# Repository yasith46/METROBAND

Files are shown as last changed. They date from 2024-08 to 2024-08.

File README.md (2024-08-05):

<div align="center">  
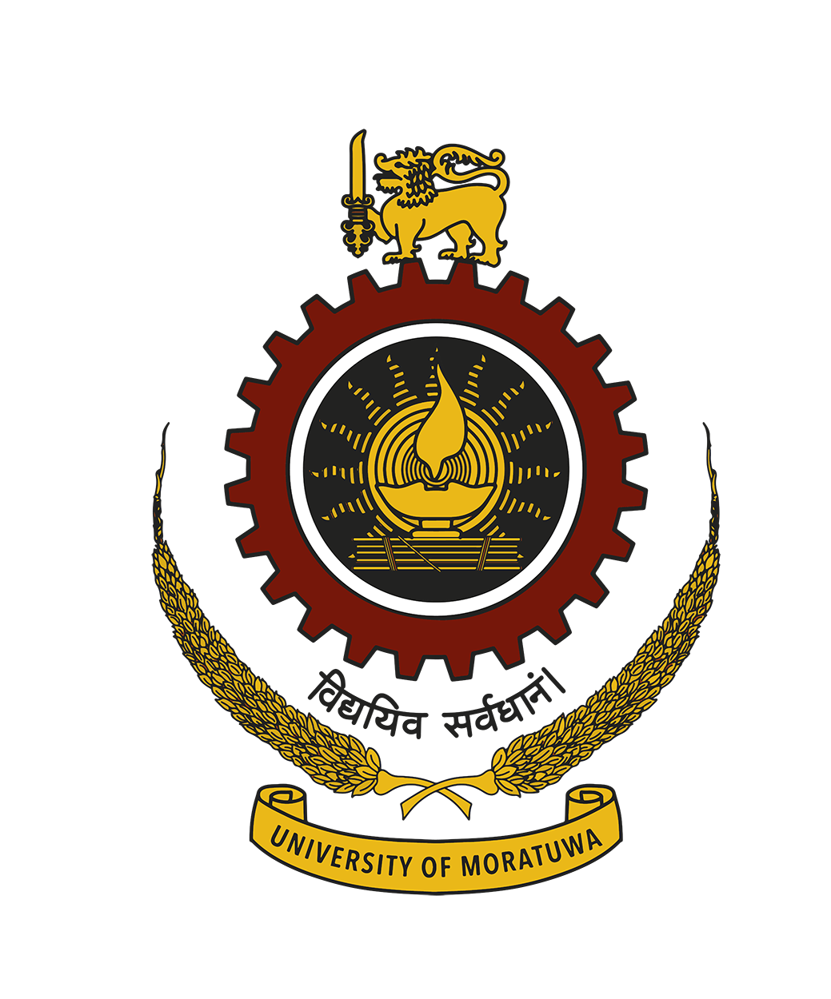
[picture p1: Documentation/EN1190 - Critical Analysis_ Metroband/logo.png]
    
    <h4>Department of Electronics and Telecommunications<br>University of Moratuwa</h4>
    <h2> METROBAND - The Metronome Wristband</h2>
    <br>Done in partial fulfillment of the requirements for the module <i>EN 1190 Engineering Design Project</i>
</div>

<br>Aim of this project is to create an alternative to the traditional Metronome, with a digitally controlled vibrating wristband. This repository contains all the documentation, code, schematics, PCB designs, and simulations of the project.
<br>Above works were done by Yasith Silva ([@yasith46](https://github.com/yasith46)), Bimsara Nawarathne ([@bimsaranawa](https://github.com/bimsaranawa)), Isuranga Senavirathne ([@isuranga1](https://github.com/isuranga1)) and Julian Silva ([@JulianSilva2001](https://github.com/JulianSilva2001)).

Demonstration of the project:<br><br>
<div align="center">
    <h3>Demonstration of the project:</h3><br>
    <a href="https://www.youtube.com/watch?v=N5GJq5FccDs" target="_blank">
        Demonstration of the Final Product
    </a>
</div>

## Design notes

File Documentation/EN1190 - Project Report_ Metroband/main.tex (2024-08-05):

\documentclass{article}
\usepackage{titlesec}
\usepackage[utf8]{inputenc}
\usepackage[a4paper, total={6in, 9in}]{geometry}
\usepackage{fancyhdr}
\usepackage{graphicx} % Add the graphicx package
\usepackage{lipsum} % For placeholder text
\usepackage{tikz}
\usepackage{cite}
\usepackage{bm}
\usepackage{acronym}
\usepackage{amsmath,amssymb,amsfonts}
\usepackage{algorithmic}
\usepackage{graphicx}
\usepackage{caption}
\usepackage{subcaption}
\captionsetup{font=small, labelfont=bf}
\captionsetup[sub]{labelsep=period, subrefformat=brace}
\usepackage{tikz}
\usepackage{textcomp}
\usepackage{xcolor}
\usepackage[numbers]{natbib}
\bibliographystyle{ieeetrann}
\usepackage{subfig}
\usepackage{svg}
\usepackage{tikz,pgfplots,pgfplotstable}
\pgfplotsset{compat=1.9} % set to 1.8 to get old behaviour
\usepackage{subfigure}
\usepackage{paralist}
\usepackage{longtable}

% Set up page headers and footers
\pagestyle{fancy}
\fancyhf{}
\rhead{ }
\rhead{team MOSFETS}
\lhead{Metroband - The Metronome Wristband}
\cfoot{\thepage}

% Redefine the abstract environment to be single column
\renewenvironment{abstract}
{\par\noindent\textbf{\abstractname}\ \ignorespaces}{\par}

% Redefine section format
\titleformat{\section}
{\normalfont\Large\bfseries}{\thesection}{1em}{}

\begin{document}
	
	% Cover Page
	\begin{titlepage}
		
		\centering
		\vspace*{0.5cm}
		 % Replace with the path to your university logo
		\par\vspace{0.02cm}
		Department of Electronic \& Telecommunication Engineering
  
            University of Moratuwa, Sri Lanka.
		\par\vspace{4cm}
		{\LARGE\bfseries Project Report:}\\{\LARGE Metroband - The Metronome Wristband\par}
		\vspace{4cm}
		\begin{tabular}{l l}
			& \\
            \multicolumn{2}{c}{\textbf{team MOSFETS}}\\
            210415N	&	Navarathne D.M.G.B.\\
            210594J &	Senevirathne I.U.B.\\
            210608J &	Silva L.J.J.P.\\
            210609M	&	Silva M.K.Y.U.N. \\
		\end{tabular}\\
		\vspace{1.3cm}
            {Submitted in partial fulfillment of the requirements for the module\par}
		{EN 1190 Engineering Design Project\par}
	
		\vspace{0.5cm}
		{\large 06/08/2024\par}
		\vfill
	\end{titlepage}

        \newpage
        \tableofcontents
	\newpage
	
        \section{Introduction}
        The aim of this project is to design and develop a pulsating wristband according to a given BPM to give a better experience for beginner, intermediate or professional musicians. This project is undertaken by a team of four engineering undergraduates from the University of Moratuwa. The following report provides details of the progress made towards achieving the project objectives.
        
        \subsection{The Problem, and the Motivation to Solve it}
        \subsubsection{Problem Definition}
        In music, BPM is the speed of a musical piece. It determines the overall energy and the feel of the musical performance. It is measured in Beats per Minute (BPM). In practicing to master a piece, it is crucial for one to be able to play it in time. This is even more important when playing in groups, where the whole group must play it at the same BPM. It is often maintained throughout the music using a metronome, in-ear headphones, or a conductor.\\

        One of the major problems of musicians of both beginner and amateur levels, and sometimes even professionals is, keeping up the BPM while performing or practicing. For beginners, it brings great frustration as well as for many others when performing with a group it ruins the entire timing of the song. This often wastes a good fraction of the practice time.\\

        There are a few solutions to combat this. Namely:
        \begin{compactitem}
                \item Metronomes
                \item In-ear Headphones
        \end{compactitem}
        .\\
        But they too have their own potential problems and limitations which are listed below that have been complained about by many users:

        \begin{itemize}
                \item \textbf{External noise:} In noisy environments, metronomes can be hard to hear, and in-ear headphones can isolate the player from outside sounds, making it challenging to play with others.
                \item \textbf{Distraction:} Some musicians may find metronomes to be distracting or irritating, especially if they are practicing for extended periods of time. Over time, in-ear headphones may also result in ear discomfort or tiredness.
                \item \textbf{Inaccessibility:} Due to physical constraints or disabilities like hearing impairments, some musicians may find it challenging to utilize conventional metronomes or headphones, which have been recognized as a major issue.
                \item \textbf{Cost:} Metronomes and in-ear headphones can be expensive which will not make it feasible for many users.
        \end{itemize}

        \subsubsection{Motivation for our solution}
        Since all our group members are practicing music up to some extent, we have all felt the need of addressing this problem. However, to gather more information about this matter we carried out an online survey which spanned out not only through local music societies but also across multiple global music societies as well. The communities from which we gathered information are as follows:

        \begin{compactitem}
                \item Classical Music Society (CMS) of the University of Moratuwa
                \item Discord servers such as ‘We are engineers’ of Mattias Krantz and ‘RoomieOfficial’ of Joel Berghult; two popular Swedish music YouTubers
                \item Peer musician groups
                \item Social media such as X (formerly Twitter) and Facebook
                \item Personal contacts
        \end{compactitem}

        \newpage
        The results of our survey are as follows:

        \begin{figure}[htpb]
            \centering
            \begin{minipage}{0.45\textwidth}
                \centering
                \begin{subfigure}{\textwidth}
                    \centering
                    \begin{tikzpicture}
                        \begin{axis}[
                            ybar stacked,
                            width=7cm,
                            xlabel={Categories},
                            ylabel={Values},
                            legend style={at={(0.5,-0.65)}, anchor=north, legend columns=2},
                            symbolic x coords={Very Hard, Hard, Neutral, Easy, Very Easy},
                            xtick=data,
                            x tick label style={rotate=45, anchor=east, xshift=-1.5mm, yshift=-2mm},
                            nodes near coords={},
                            nodes near coords align={vertical},
                            ]
                            \addplot+[bar width=0.4cm] coordinates {(Very Hard, 0) (Hard, 1) (Neutral, 3) (Easy, 0) (Very Easy, 2)};
                            \addplot+[bar width=0.4cm] coordinates {(Very Hard, 2) (Hard, 3) (Neutral, 7) (Easy, 6) (Very Easy, 0)};
                            \addplot+[bar width=0.4cm] coordinates {(Very Hard, 1) (Hard, 4) (Neutral, 18) (Easy, 27) (Very Easy, 7)};
                            \addplot+[bar width=0.4cm] coordinates {(Very Hard, 0) (Hard, 0) (Neutral, 1) (Easy, 4) (Very Easy, 1)};
                            \legend{Played in past, Beginner, Intermediate, Professional}
                        \end{axis}
                    \end{tikzpicture}
                \end{subfigure}
            \end{minipage}
            \hspace{1cm}
            \begin{minipage}{0.45\textwidth}
                \centering
                \begin{subfigure}{\textwidth}
                    \centering
                    \begin{tikzpicture}
                        \begin{axis}[
                            ybar stacked,
                            width=7cm,
                            xlabel={Categories},
                            ylabel={Values},
                            legend style={at={(0.5,-0.65)}, anchor=north, legend columns=2},
                            symbolic x coords={Very Ineffective, Ineffective, Neutral, Effective, Very Effective},
                            xtick=data,
                            x tick label style={rotate=45, anchor=east, xshift=-1.5mm, yshift=-2mm},
                            nodes near coords={},
                            nodes near coords align={vertical},
                            ]
                            \addplot+[bar width=0.4cm] coordinates {(Very Ineffective, 1) (Ineffective, 1) (Neutral, 2) (Effective, 0) (Very Effective, 0)};
                            \addplot+[bar width=0.4cm] coordinates {(Very Ineffective, 1) (Ineffective, 0) (Neutral, 4) (Effective, 4) (Very Effective, 2)};
                            \addplot+[bar width=0.4cm] coordinates {(Very Ineffective, 6) (Ineffective, 8) (Neutral, 3) (Effective, 17) (Very Effective, 14)};
                            \addplot+[bar width=0.4cm] coordinates {(Very Ineffective, 0) (Ineffective, 0) (Neutral, 1) (Effective, 1) (Very Effective, 4)};
                            \legend{Played in past, Beginner, Intermediate, Professional}
                        \end{axis}
                    \end{tikzpicture}
                \end{subfigure}
            \end{minipage}
            \caption{Comparison of Stacked Bar Charts A and B}
        \end{figure}

        \subsection{Our Solution}
        As a solution to these critical problems and limitations that have arisen, after thorough observation and research, we have decided that the best solution would be a wristband that is pulsating according to a given BPM which we named \textbf{‘Metroband’}. The reasonings for our solution are listed as follows:

        \begin{itemize}
                \item \textbf{Convenience:} A wristband is portable and wearable, so it can be used anywhere and anytime without the need for a separate device. This can be especially useful for musicians who need to maintain a consistent BPM while on the go, such as during rehearsals or performances.
                \item \textbf{Discreetness:} A vibrating wristband produces a subtle, tactile cue that only the wearer can feel, unlike a metronome which produces an audible sound that can be distracting or disruptive in certain settings, such as recording studios or quiet performance venues.
                \item \textbf{Personalization:} A wristband can be personalized to the user's preferences, allowing them to set their own BPM and adjust the intensity of the vibrations to match their playing style or musical genre.
                \item \textbf{Accessibility:} A wristband can be a useful tool for musicians with hearing impairments or who prefer to play without auditory distractions, as it provides a non-auditory way to keep track of the BPM.
        \end{itemize}

        \section{Technical feasibility}
        The physical appearance of the Metroband would be similar to a smartwatch which could be easily worn on the wrist with simply one knob to do all the operations. Moving onto the internal structure of the Metroband, it is basically built around a single dual-core microcontroller that takes inputs from the knob and displays the relevant BPM on an LCD display. All these devices are powered by a rechargeable Lithium-Ion battery.\\
        
        The required components such as ESP32, rotary encoders, LCD TFT displays, MCP73831 are readily available on the market, both on online vendors as well through local sellers. Further, thorough documentation of these components is available online.\\
        
        We have planned on to programme the ESP32 using another ESP32 Development Kit, using the Arduino IDE. Due to the availability of well optimized free and open-source libraries, the implementation of Bluetooth can be done way far more efficiently.

        \section{Product Architecture}
        Below shown is a block diagram of the abstract modules in the Metroband. It has clearly mentioned the connections, data flow directions, and some data on what data are communicated between the modules that  are described earlier.

            \begin{figure}[!htb]
                \centering
                \begin{tikzpicture}
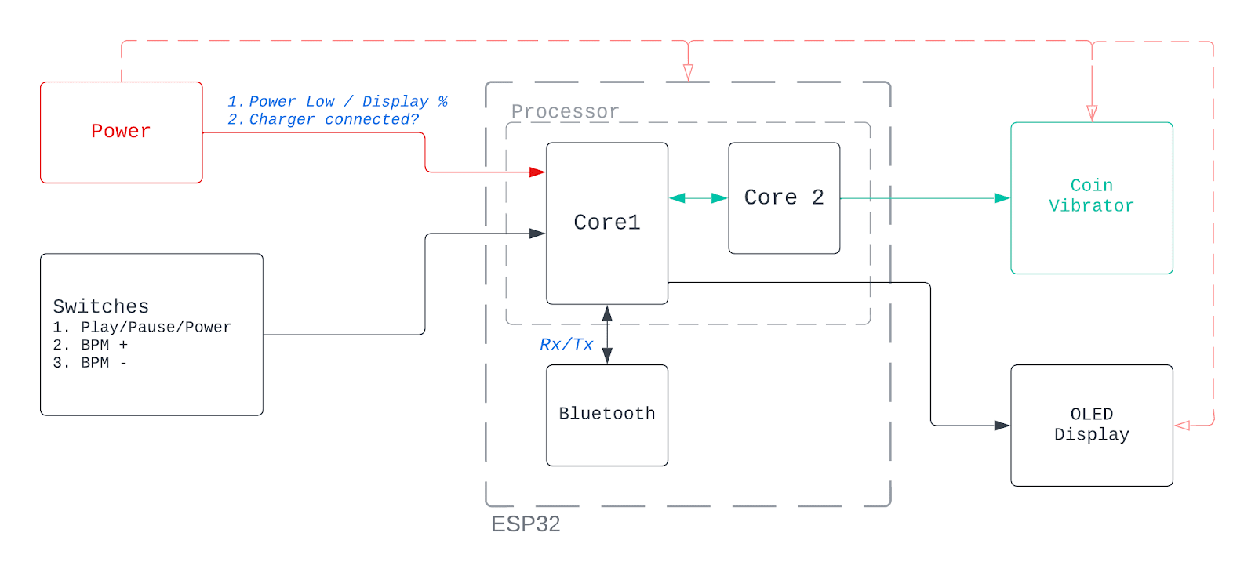
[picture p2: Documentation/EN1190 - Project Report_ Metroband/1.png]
                    \node at (0.5,-0.2){};
                \end{tikzpicture}
                \caption{Product architecture}
            \end{figure}

        Functionalities of each module is as follows:
        \subsection{ESP32 Micro-controller}
        This is the microcontroller that we will be using for our product. Each operation is split into tasks, and the ESP32 executes them according to the priority set by the code. Also, the Bluetooth module allows the device to communicate with the mobile app.

        \subsection{Switches}
        As the switch we are using a rotary encoder. Mainly because it can be used to many functionalities. By rotating it clockwise and counterclockwise, we can increase or decrease the BPM. By pressing and depressing it, we can play/pause sending pulses to the vibrating motor. Long press will switch on/off the devices.

        \subsection{LCD TFT Display}
        This will be the display used to mainly show the BPM. Other than that, it will show the Bluetooth connectivity and battery percentage as well.

        \subsection{Coin Vibrator}
        This is the vibrating motor used in our device. It vibrates according to the pulses sent by the microcontroller. In fact, the pulses will be sent through a transistor in switch mode which will give the full power of the battery to the motor.

        \subsection{Power}
        We will be using a rechargeable Lithium-Ion battery to power up all the devices in our product. To handle the charging process, there will be charging IC as well.

        \section{Sketches}
        \subsection{Initial Sketches}
            \begin{figure}[!htb]
                \centering
                \begin{tikzpicture}
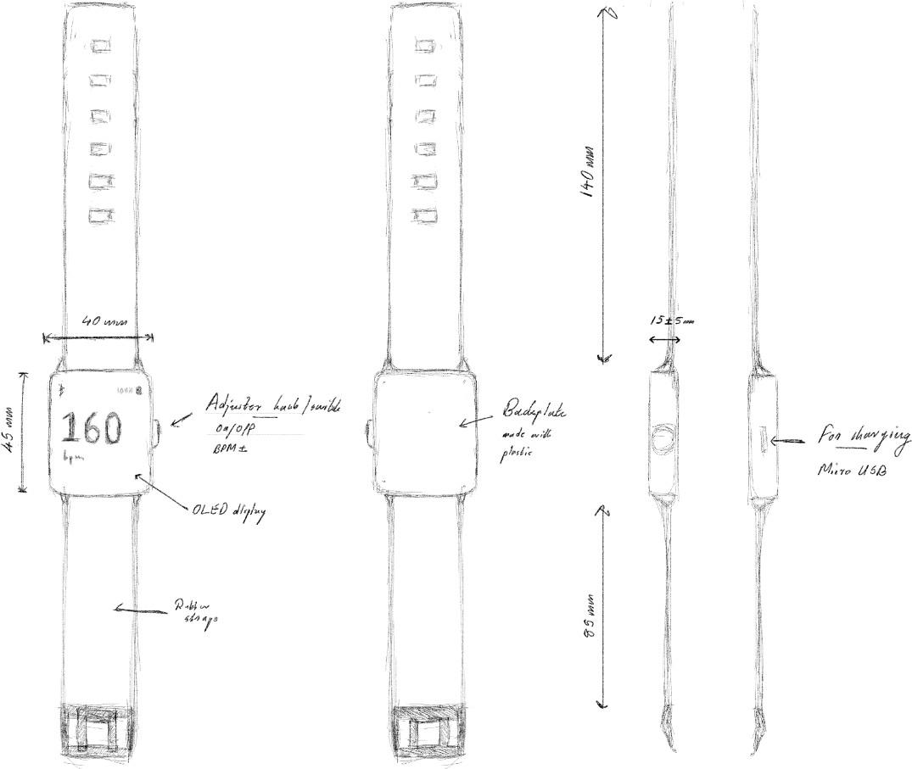
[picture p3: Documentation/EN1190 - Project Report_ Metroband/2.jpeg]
                    \node at (0.5,-0.2){};
                \end{tikzpicture}
                \caption{Initial sketch}
            \end{figure}

        \subsection{Final Design}

        \begin{minipage}{\linewidth}
                \centering
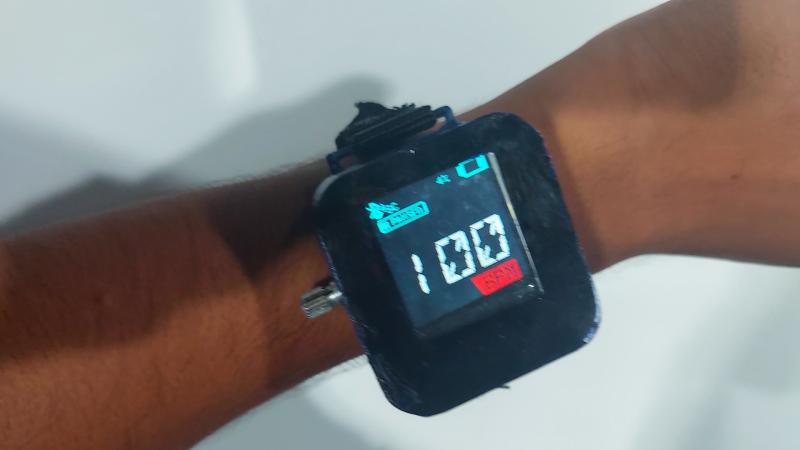
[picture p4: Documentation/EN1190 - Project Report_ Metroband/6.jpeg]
                
                \hspace{0.005\linewidth}
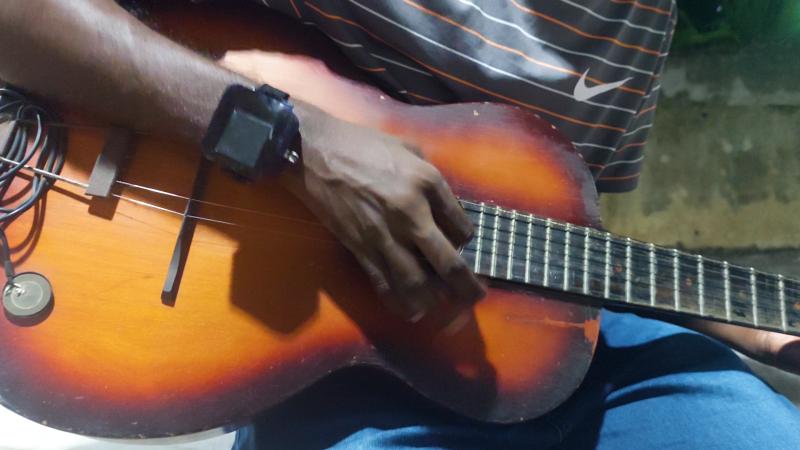
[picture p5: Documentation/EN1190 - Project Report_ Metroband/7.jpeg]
                
                \captionsetup{justification=centering} % Center-align the caption
                \captionof{figure}{Final design, worn on hand}
            \end{minipage}

        \section{Finalized Project Details}
        \subsection{Schematic and PCB}
        \begin{figure}[!htb]
                \centering
                \begin{tikzpicture}
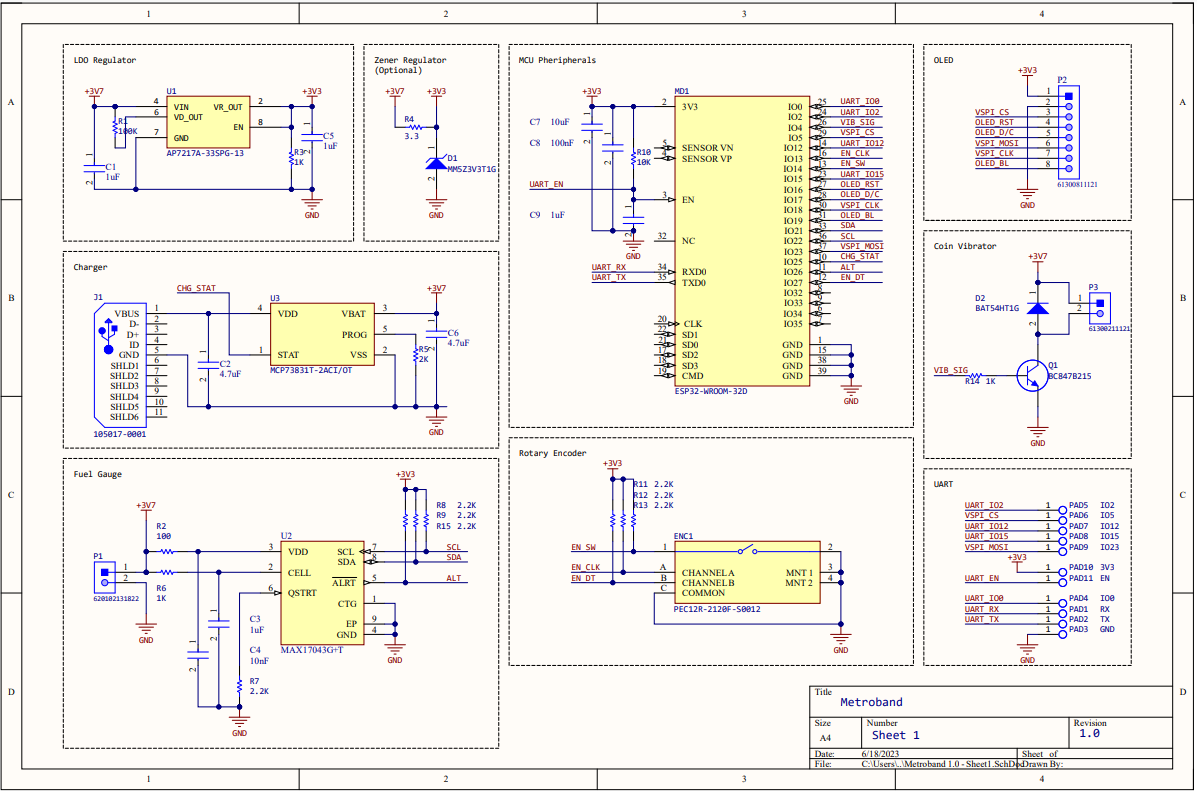
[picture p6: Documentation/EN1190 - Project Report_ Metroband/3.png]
                    \node at (0.5,-0.2){};
                \end{tikzpicture}
                \caption{Schematic Diagram}
                \label{schematic}
            \end{figure}
        \begin{figure}[!htb]
                \centering
                \begin{tikzpicture}
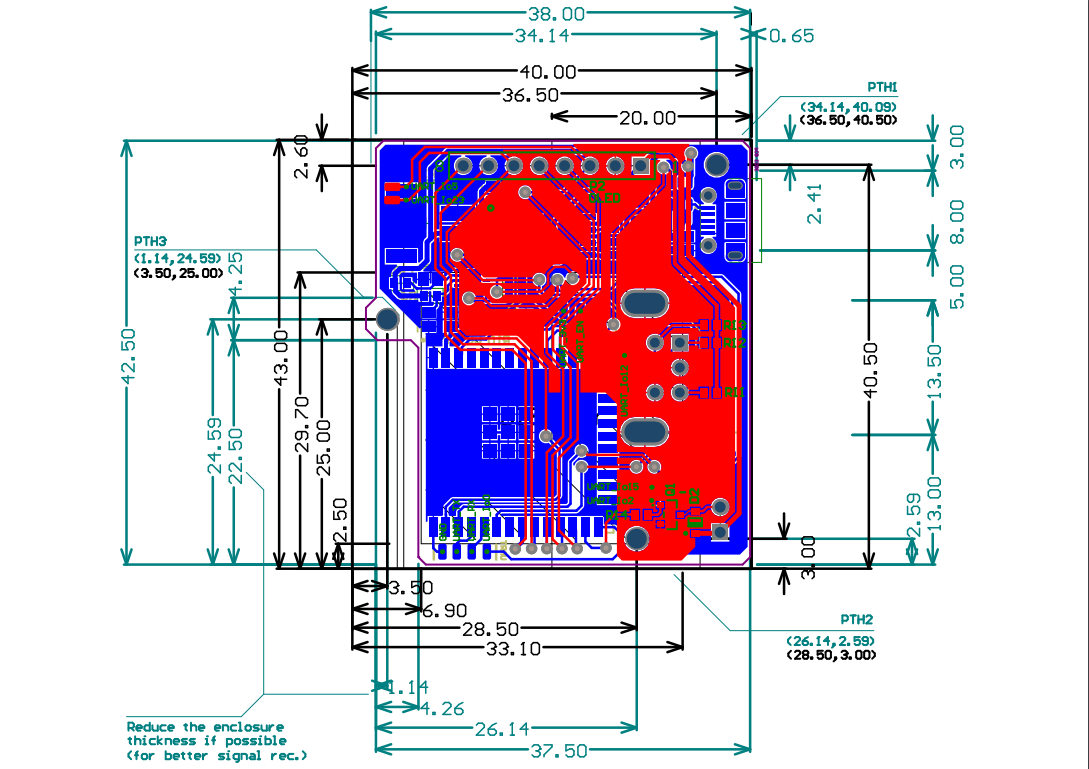
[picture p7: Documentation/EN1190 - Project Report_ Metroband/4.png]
                    \node at (0.5,-0.2){};
                \end{tikzpicture}
                \caption{PCB overview}
                \label{pcb}
            \end{figure}
        \begin{figure}[!htb]
                \centering
                \begin{tikzpicture}
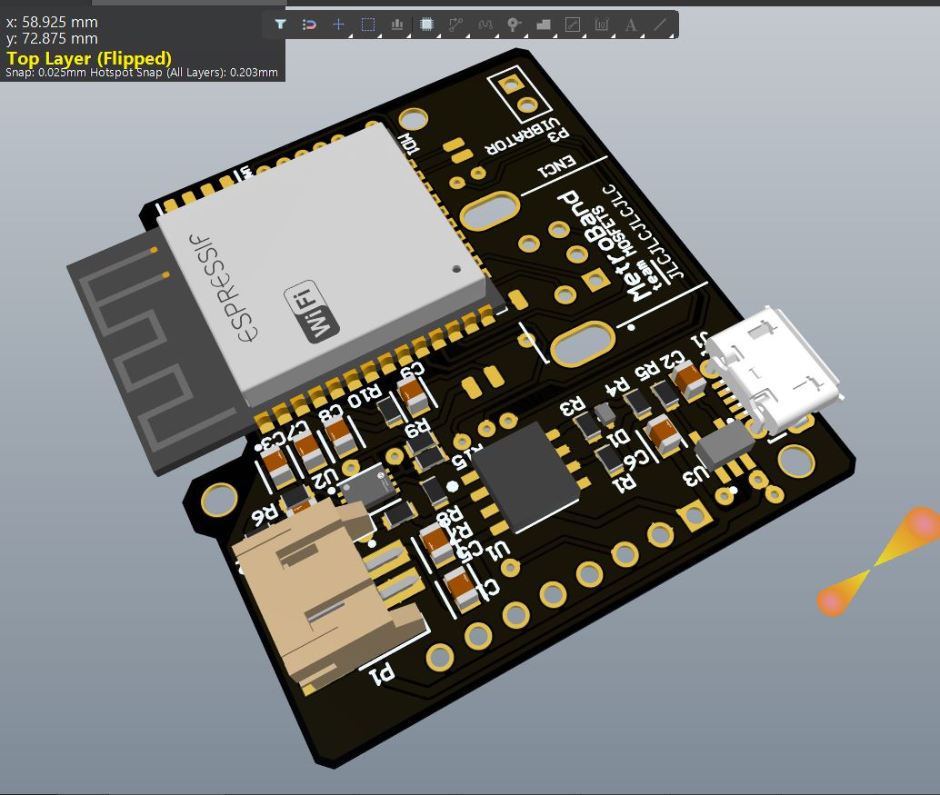
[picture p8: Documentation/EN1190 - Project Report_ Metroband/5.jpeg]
                    \node at (0.5,-0.2){};
                \end{tikzpicture}
                \caption{3D view of the PCB}
                \label{pcb3d}
            \end{figure}
        The circuit diagram of the product is shown below in Figure \ref{schematic}. It was designed with a voltage regulator as the battery gives a voltage of 4.2V when fully charged, and the ESP32 requires 3.6-2.2V. Although the IC was included in the circuit, due to predictions of local unavailability of the ICs we included a slot for a zener diode of 3.3V to be soldered as well.\\
        
        Several modifications were done for the display, as we chose a TFT display rather than an OLED display.\\
        
        All the functionalities of the circuit are controlled by the rotary encoder and its inbuilt push-button (manually) and via bluetooth.\\
        
        The PCB in size is 42.5mm x 38mm as it requires to be small enough to fit on a wrist. Hence it was required to use SMD components. also the required clearances for the antenna of the ESP32 were kept. ESP32 was planned to be programmed with the UART converter of a development board, and for this purpose several test pads were kept so wires could be soldered and it desoldered at the last minute.

        \subsection{Coding}
        For coding we used the ESP IDF. We carried out the tasks separately in the singular core rather than carrying all the tasks in a singular loop while adjusting their priorities.
        Also we had to use multiple libraries in order to code the parts related to bluetooth, display and other functions of the ESP32. Further, we had to design the bitmap of the icons as well as the numbers, as we used a 16-segment display font.

        \subsection{Enclosure Design}
        The enclosure was designed using SOLIDWORKS 2023.We needed to get the enclosure as detailed as possible with minimum dimensions.\\

        \begin{minipage}{\linewidth}
                \centering
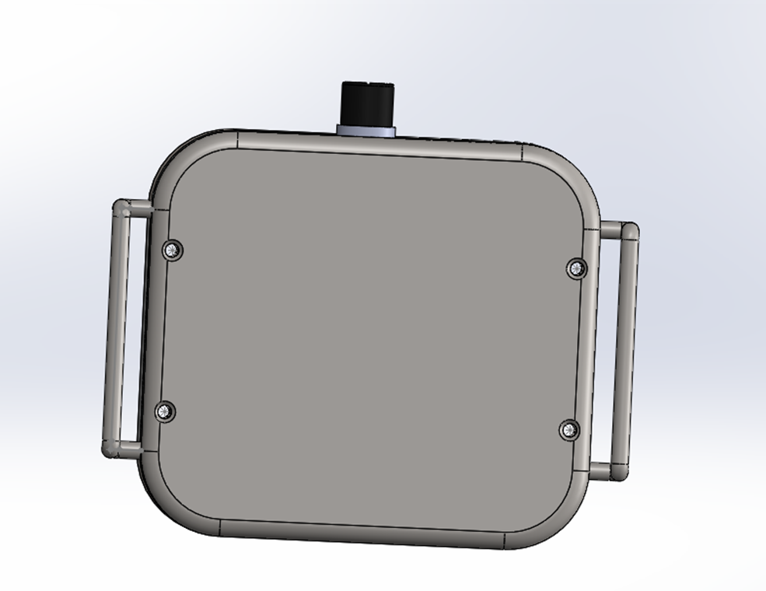
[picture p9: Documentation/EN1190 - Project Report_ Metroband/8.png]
                
                \hspace{0.005\linewidth}
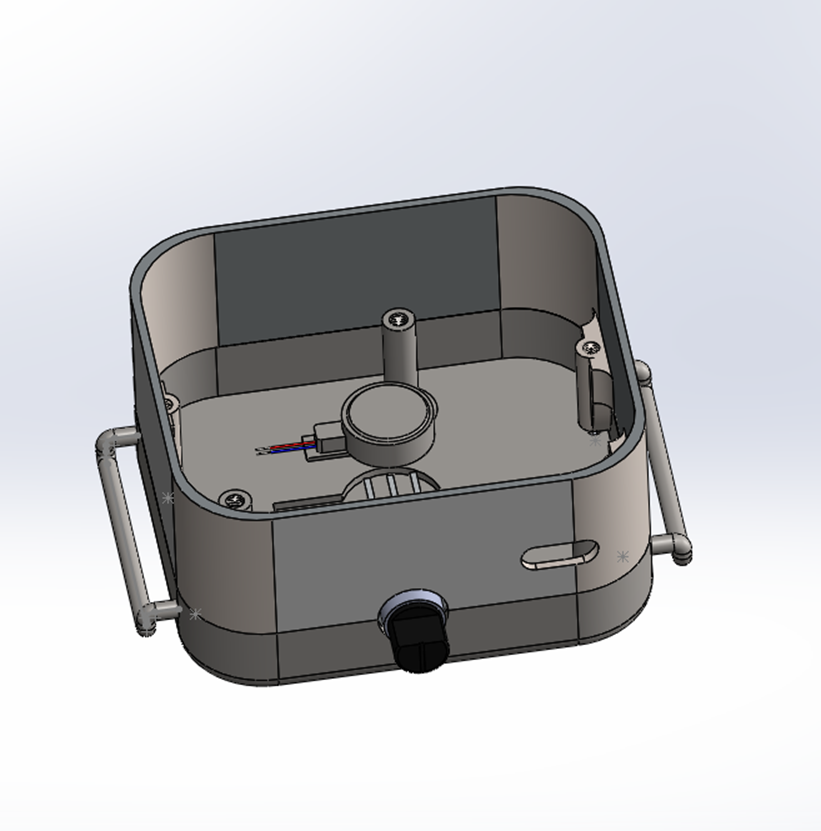
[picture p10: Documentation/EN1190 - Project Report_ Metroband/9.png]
                
                \hspace{0.005\linewidth}
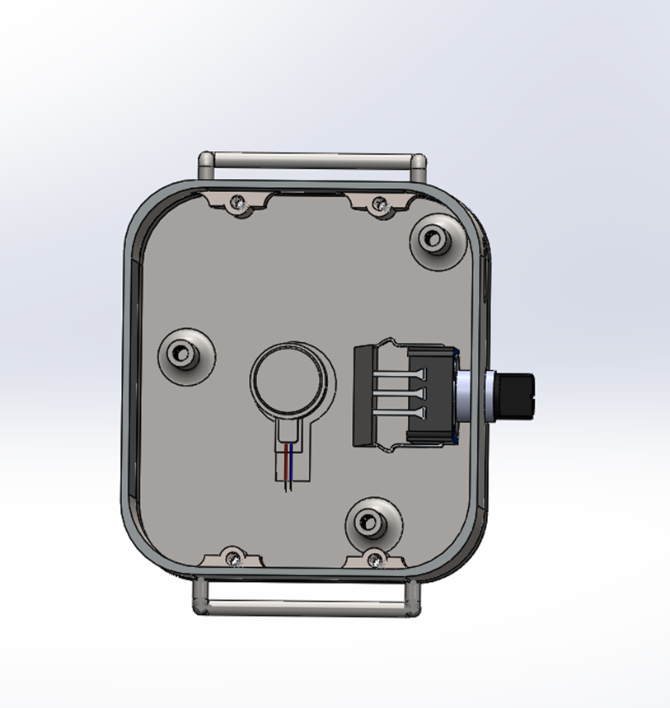
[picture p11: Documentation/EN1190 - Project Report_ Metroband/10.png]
                
                \captionsetup{justification=centering} % Center-align the caption
                \captionof{figure}{Enclosure SOLIDWORKS design}
            \end{minipage}

        \newpage
        \section{Project Budget}
        \begin{longtable}{|l|r|r|r|}
        
        \hline
        \textbf{Item} & \textbf{Quantity} & \textbf{Unit Price} & \textbf{Price} \\
        \hline
        \endfirsthead
        
        \hline
        \textbf{Item} & \textbf{Quantity} & \textbf{Unit Price} & \textbf{Price} \\
        \hline
        \endhead
        
        \hline
        \endfoot
        
        \hline
        \endlastfoot
        
        Coin vibrator & 1 & RS.300 & RS.300 \\
        Battery & 1 & Rs.450 & Rs.450 \\
        TFT display unit & 1 & Rs.1400 & Rs.1400 \\
        Regulator IC & 1 & Rs.185 & Rs.185 \\
        Fuel gauge IC & 1 & Rs.500 & Rs.500 \\
        Charger IC & 1 & Rs.350 & Rs.350 \\
        mini USB slot & 1 & Rs.150 & Rs.150 \\
        PCB Design and Printing & - & - & Rs.500 \\
        Enclosure Printing & - & - & Rs.760 \\
        Padding and Straps & - & - & Rs.250 \\
        Resistors & 6 & - & Rs.50 \\
        Capacitors & 8 & - & Rs.50 \\
        Transistor & 1 & Rs.5 & Rs.5 \\
        Esp 32 module & 1 & Rs.700 & Rs.700 \\
        Rotary Encoder & 1 & Rs.350 & Rs.350 \\
        \hline
        \textbf{Total cost for components} & - & - & \textbf{Rs.5995.00} \\
        \textbf{Number of units} & - & - & \textbf{200} \\
        \textbf{Marketing and sales cost} & - & - & \textbf{Rs.10,000} \\
        \textbf{Profit per unit} & - & - & \textbf{Rs.5000} \\
        \textbf{Product price} & - & - & \textbf{Rs.10,000} \\
        \hline
        \end{longtable}

        \section{Future Developments}
        \subsection{Size}
        Currently we have identified that the size of the prototype could be a hindrance for some musicians. Hence we intend to reduce the size of the watch to a wearable size. In order to do this we have come across few methods:
        \begin{itemize}
                \item Using a TFT display without the breakout PCB, as the PCB and the pin headers add 3 mm to the height
                \item By using a smaller rotary encoder which is usually used in applications such as smartwatches, we can further reduce the height
                \item By resorting to a further compact design in designing the PCB, and outsourcing the soldering of components to a ‘pick and place’ services provider, the length and width of the apparatus could be reduced
                \item By choosing a thinner battery, the height could be further reduced
        \end{itemize}

        \subsection{Display}
        Currently we have included a 1.44 inch TFT. As this does not cover the complete front face of the watch, we have identified that it would be better to choose a display slightly larger than the current display, which would be rather aesthetically pleasing to the consumer.\\
        Further, the current display elements are designed in such a way so they are reminiscent of the classic ‘Vacuum Fluorescent Displays’, which would be further improved in the design phase to further resemble.

        \subsection{Vibration Intensity}
        For musicians who play rather delicate instruments such as piano or violin, more subtle vibrations are required. And some users would need a user set vibration intensity for the device to vibrate with. For this, we have identified using a PWM signal with an adjustable duty cycle as a solution. The code will be changed accordingly to achieve this, and a setting to change the intensity would be added to the mobile app. 

        \subsection{USB C port}
        Recently, USB-C has become the standard connector for the devices. Hence USB-C cables are becoming more available. Hence by changing the Micro-USB to a USB-C port, we give the consumer the opportunity to use any charging cable as they would please.

        \subsection{Battery}
        With the current battery, the device’s charge remains up to 5 hours when in use. This could be further improved with using a battery with a better capacity, while retaining (or preferably reducing) the size.

        \subsection{Enclosure}
        The enclosure will have a design makeover, with a newer, more attractive design which suits the modern market. The straps would be replaced with more comfortable silicone straps, and the body would have a more sleek design.

        \subsection{Mobile Application}
        The app is to be  featured with additional features. The vibration intensity can be set by the mobile app which will make it feasible for playing different instruments that require different vibration intensities. Moreover, presets can be saved in the mobile app so that the Metroband can help the musicians in playing music that changes its beat in-between or  gradually. Additionally, playlists can be saved in the mobile app. Also the UI design will be improved.

        \section{Marketing, Sales, and After-sales}
        \subsection{Marketing}
        We’ll be focusing our marketing effort on musicians, music students, choirs and orchestras. The silent and convenient alternative to traditional metronomes, allowing for uninterrupted practice sessions will be highlighted which will be offered by the “Metroband”.\\
        
        We’ll be engaging with online communities, forums, Facebook, WhatsApp, twitter and other social media groups that are dedicated to musicians and music enthusiasts. We will be participating in discussions, sharing valuable insights while promoting the “Metroband” as a useful tool not only for the musicians seeking an innovative way to keep the BPM without the noise, but also for the musicians with hearing disorders to keep up their beat in time.\\
        
        We’ll be also creating engaging creative videos that demonstrate the functionality, the benefits and the need of the “Metroband” for the musicians. Moreover, how the wristband can be synchronized with various instruments and used during practice sessions can be shown. These videos will be shared on our website and social media platforms.\\
        
        Also we were able to present our product at the EXMO exhibition which was held on 27th to 29th of July, which gave a great exposure for our product, which also gave us the opportunity to connect with potential investors.

        \subsection{After-sales}
        Encourage the customers to provide feedback and testimonials about their experience using the “Metroband”. Positive reviews can be highlighted and posted on social media channels to gain the trust and attract new customers. Negative reviews will be carefully comprehended, and prompt actions will be taken to resolve them.\\
        
        Because the ESP32 board is used here we are able to code it so that it is able to receive over the air firmware updates (OTA updates). Because of this even more functionalities can be added even after the sale of the product.\\
        
        The product's disposability is also taken into consideration. There will be detailed instructions on how to properly dispose of the wristbands, including details on recycling possibilities. Any harmful or poisonous materials can be reused or given to electronic shops for reuse because they are not used in the electronic component. Additionally, details will be provided on how customers can return straps so that we can recycle or re-purpose them.\\

        \section{Task Allocation}

        \begin{itemize}
            \item \textbf{Nawarathna D.M.G.B}
                \begin{itemize}
                    \item Coding
                    \item PCB Design
                    \item Vibrating Motor Module
                \end{itemize}

            \item \textbf{Senevirathne I.U.B}
                \begin{itemize}
                    \item OLED Display Module
                    \item Web App Development
                    \item Budget Management
                    \item Enclosure Design
                \end{itemize}

            \item \textbf{Silva L.J.J.P}
                \begin{itemize}
                    \item Microcontroller and the Peripherals
                    \item Enclosure Design
                    \item Market Research
                \end{itemize}
        
            \item \textbf{Silva M.K.Y.U.N}
                \begin{itemize}
                    \item PCB Design
                    \item Schematic
                    \item Fuel Gauge 
                    \item Coding
                \end{itemize}
        \end{itemize}

\end{document}

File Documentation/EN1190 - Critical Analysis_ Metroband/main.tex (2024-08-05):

\documentclass{article}
\usepackage{titlesec}
\usepackage[utf8]{inputenc}
\usepackage[a4paper, total={6in, 9in}]{geometry}
\usepackage{fancyhdr}
\usepackage{graphicx} % Add the graphicx package
\usepackage{lipsum} % For placeholder text
\usepackage{tikz}
\usepackage{cite}
\usepackage{bm}
\usepackage{acronym}
\usepackage{amsmath,amssymb,amsfonts}
\usepackage{algorithmic}
\usepackage{graphicx}
\usepackage{caption}
\usepackage{subcaption}
\captionsetup{font=small, labelfont=bf}
\captionsetup[sub]{labelsep=period, subrefformat=brace}
\usepackage{tikz}
\usepackage{textcomp}
\usepackage{xcolor}
\usepackage[numbers]{natbib}
\bibliographystyle{ieeetrann}
\usepackage{subfig}
\usepackage{svg}
\usepackage{tikz,pgfplots,pgfplotstable}
\pgfplotsset{compat=1.9} % set to 1.8 to get old behaviour
\usepackage{subfigure}
\usepackage{paralist}
\usepackage{longtable}

% Set up page headers and footers
\pagestyle{fancy}
\fancyhf{}
\rhead{ }
\rhead{team MOSFETS}
\lhead{Metroband - The Metronome Wristband}
\cfoot{\thepage}

% Redefine the abstract environment to be single column
\renewenvironment{abstract}
{\par\noindent\textbf{\abstractname}\ \ignorespaces}{\par}

% Redefine section format
\titleformat{\section}
{\normalfont\Large\bfseries}{\thesection}{1em}{}

\begin{document}
	
	% Cover Page
	\begin{titlepage}
		
		\centering
		\vspace*{0.5cm}
		 % Replace with the path to your university logo
		\par\vspace{0.02cm}
		Department of Electronic \& Telecommunication Engineering
  
            University of Moratuwa, Sri Lanka.
		\par\vspace{4cm}
		{\LARGE\bfseries Critical Analysis:}\\{\LARGE Metroband\par}
		\vspace{4cm}
		\begin{tabular}{l l}
			& \\
            \multicolumn{2}{c}{\textbf{team MOSFETS}}\\
            210415N	&	Navarathne D.M.G.B.\\
            210594J &	Senevirathne I.U.B.\\
            210608J &	Silva L.J.J.P.\\
            210609M	&	Silva M.K.Y.U.N. \\
		\end{tabular}\\
		\vspace{1.3cm}
            {Submitted in partial fulfillment of the requirements for the module\par}
		{EN 1190 Engineering Design Project\par}
	
		\vspace{0.5cm}
		{\large 08/05/2024\par}
		\vfill
	\end{titlepage}

        \newpage
        The following report provides a critical analysis of the project for the design and development of the Metroband. The project aims to create a wristband that can pulse in sync with the tempo, providing a novel and engaging user experience. The design incorporates a microcontroller, a vibrating motor, and a display unit, all housed in a compact and comfortable wristband. The purpose of this report is to evaluate the success of the project in meeting its goals, as well as to identify any areas for improvement or further development.\\

        Below mentioned are the probable constraints and the suggested solutions to overcome:
        
        \section{Battery life}
        DC motors usually draw some more current than other components, specifically in the start of the rotation. Vibrator is something having a similar mechanism to a motor, and in giving the tempo it would have to start up the rotation several times corresponding to the Beats per Minute value. Hence it might draw a larger current, which might not be a good thing for some components, as well as drain the batteries quicker.\\
        
        This can be overcome by using the following strategies. 

        \subsection{Using Low power Bluetooth - built-in Bluetooth Low Energy chip in ESP32}

        \begin{figure}[!htb]
                \centering
                \begin{tikzpicture}
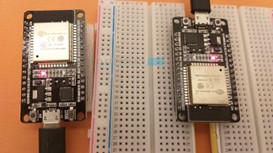
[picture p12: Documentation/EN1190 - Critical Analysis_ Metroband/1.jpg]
                    \node at (0.5,-0.2){};
                \end{tikzpicture}
            \end{figure}

        Why the built-in Bluetooth Low Energy chip in ESP32? 
        \begin{itemize}
            \item \textbf{Low power consumption:} \\
            Bluetooth Low Energy is designed to be highly energy-efficient, allowing devices to operate on a small battery for long periods of time. This makes it the best suited communication protocol for low-power devices like the ESP32.

            \item \textbf{Short-range communication:}\\ 
            BLE is designed for short-range communication, which means that it is ideal for use in the “Metroband”.

            \item \textbf{Compatibility:} \\ 
            BLE is widely adopted and supported by most modern smartphones, making it easy to communicate with a wide range of devices.

            \item \textbf{Easy to use:} \\
            Can easily add wireless communication to the project without the need for additional hardware because of the built-in BLE chip.
        \end{itemize}

        Related problems and the solutions:
        \begin{itemize}
            \item \textbf{Interference:} \\
            BLE operates in the same frequency band as other wireless devices, which means that it may be subject to interference from other wireless signals. But the frequency ranges that are probable in concerts and bands do not belong to the range of the BLE frequency range. Also, Bluetooth is used in this device to send a unit pulse which will not be much affected by the other signals. For example:
            \begin{itemize}
                \item Wireless Microphones: 516-558 MHz
                \item In-Ear Monitors: 470-952 MHz
                \item Wireless Intercom Systems: 470-698 MHz
            \end{itemize}

            \item \textbf{Complexity:} 
            BLE can be more complex to implement than other wireless communication protocols but due to in built libraries in ESP 32 Bluetooth module can be accessed easily.
        \end{itemize}

        \subsection{Better battery - Polymer 3.7V 150mAh 401530 Lithium Ion Battery}

        \begin{figure}[!htb]
                \centering
                \begin{tikzpicture}
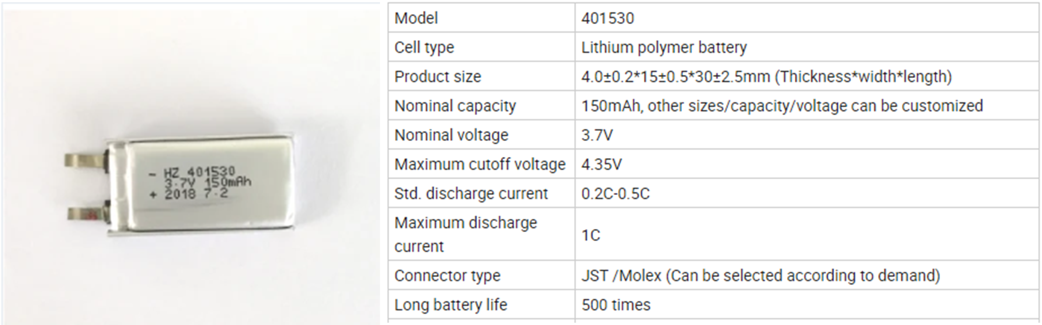
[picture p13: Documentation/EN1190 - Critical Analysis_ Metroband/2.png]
                    \node at (0.5,-0.2){};
                \end{tikzpicture}
            \end{figure}

        Why Polymer 3.7V 150mAh 401530 Lithium Ion Battery?

        \begin{itemize}
            \item \textbf{High energy density:} \\
            Polymer batteries have a higher energy density than other types of batteries, meaning they can store more energy per unit of volume, allowing for longer battery life in a small form factor.

            \item \textbf{Low self-discharge rate:} \\
            Polymer batteries have a lower self-discharge rate than other types of batteries, meaning they can hold their charge for longer periods without losing significant energy.

            \item \textbf{Lightweight and compact:}\\ 
            Polymer batteries are very lightweight and can be molded into various shapes and sizes, making them an ideal choice for small wearable devices like smartwatches.
        \end{itemize}

        Related problems and the solutions:
        \begin{itemize}
            \item \textbf{Limited lifespan and Vulnerable to high temperatures:}\\
            One solution to prolong the lifespan of the polymer battery is to avoid exposing it to high temperatures, which can cause the battery to degrade faster.  \\
            Moreover, Heats pads and ventilating slots in the enclosure can be designed to overcome the above issues. Additionally, using the correct charging method and avoiding overcharging or discharging the battery can help extend its lifespan.

            \item \textbf{Risk of overcharging:}\\ 
            To avoid overcharging the battery a TP4056 - SOIC8 - Li-on Battery Charger IC 1A is used(https://www.sunrom.com/p/tp4056-li-on-battery-charger-ic-1a). It helps prevent overcharging by using a constant-current charging method, including built-in overcharging protection, and an auto-termination feature. This helps ensure that the battery is charged safely and optimally, without the risk of overcharging.

            \begin{figure}[!htb]
                \centering
                \begin{tikzpicture}
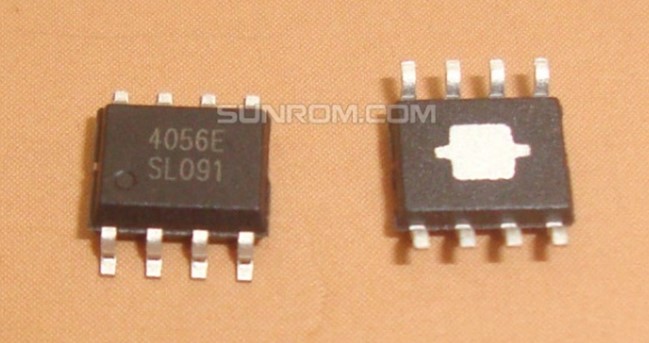
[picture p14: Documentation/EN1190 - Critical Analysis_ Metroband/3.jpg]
                    \node at (0.5,-0.2){};
                \end{tikzpicture}
            \end{figure}
            
            \item \textbf{Output voltage from the IC is not enough to drive the motor:}\\
            Output from the GPIO pins of the module can give only 40 mA when the vibration motor requires 75 mA to run, which means to start it requires an even larger current. Since connecting the motor directly to module can damage the module as well as it might result in motor not starting up at certain orientation. As a solution for this we can give the output from the module to the base of a transistor and use it as a switch.
        \end{itemize}

        \section{Timing}
        Singular core micro controller processes sequentially, but in the Metroband as we need certain tasks to be done simultaneously, we are restricted from achieving this. Moreover, it affects the processing speed as a single-core microcontroller may not be able to process data leading to slower response times and potential inaccuracies in measuring the user's BPM. Furthermore, the functionality also becomes limited as a single-core microcontroller may not have the necessary resources to handle complex algorithms or multiple inputs and outputs. \\
        
        But there is a trade off in using multicores as the power consumption increases with the increasing number of cores. \\
        
        These issues can be overcome by:
        
        \subsection{Using a Dual core microcontroller - ESP-32S WiFi Bluetooth Dual Mode Module (MD0271)}

        \begin{figure}[htpb]
                \centering
                \begin{tikzpicture}
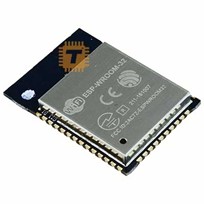
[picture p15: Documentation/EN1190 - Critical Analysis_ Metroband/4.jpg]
                    \node at (0.5,-0.2){};
                \end{tikzpicture}
            \end{figure}

        Why ESP-32S WiFi Bluetooth Dual Mode Module (MD0271)

        \begin{itemize}
            \item \textbf{Improved performance:}\\ 
            With two cores, the microcontroller can handle multiple tasks simultaneously, improving the overall performance of the wristband.
            
            \item \textbf{More functionality:} \\
            This microcontroller can handle more complex algorithms, multiple inputs, and outputs, enabling the Metroband to perform more functions than a single-core microcontroller.

            \item \textbf{Enhanced responsiveness:} \\
            With multiple cores, the wristband can more quickly respond to user inputs or changes in BPM, improving overall user experience.
        \end{itemize}

        \section{Vibrations}
        The device gives the tempo with vibrations, and since all the components need to be packed into a small compartment, other components including the PCB would constantly be subjected to vibrations. And these vibrations cannot be made less intense as that would mean it would be harder for the user to sense the vibrations.\\
        
        These issues can overcome by using these strategies:
        
        \subsection{Using High Density Polyethylene/ polypropylene or Acrylonitrile Butadiene Styrene for the back plate.}
        
        Why High-Density Polyethylene/ polypropylene or Acrylonitrile Butadiene Styrene?

        \begin{itemize}
            \item \textbf{Feels vibrations more effectively:}\\
            User feels vibrations more effectively because of their unique properties.

            \item \textbf{Durability:} \\
            HDPE, PP, and ABS are all known for their toughness and durability. They are resistant to impact, abrasion, and chemicals, making them ideal for use in a wristband that may be exposed to rough conditions or frequent use.

            \item \textbf{Lightweight:} \\
            HDPE, PP, and ABS are all lightweight materials, which can help keep the overall weight of the wristband low and comfortable to wear.

            \item \textbf{Cost-effective:} \\
            These materials are relatively inexpensive compared to other materials such as metals or composites, which can help keep the overall cost of manufacturing the wristband low.
        \end{itemize}

        \subsection{Separate the vibrating motor and the PCB with butyl rubber:}

        \begin{itemize}
            \item \textbf{Vibration isolation:} \\
            Butyl rubber is a good vibration-damping material, which means that it can absorb and dampen the vibrations produced by the motor. By isolating the motor from the PCB with butyl rubber, the vibrations are less likely to affect the electronic components on the PCB, which can help improve the reliability and longevity of the wristband.

            \item \textbf{Shock absorption:} \\
            In addition to absorbing vibrations, butyl rubber can also absorb shocks and impacts, which can be important in a wristband that may be subjected to rough handling or impacts.
            
            \item \textbf{Noise reduction:} \\ 
            By absorbing and damping the vibrations produced by the motor, butyl rubber can also help reduce the amount of noise generated by the motor, which can improve the overall user experience.
        \end{itemize}

        \subsection{Vibration motor section can be fixed to the back plate and PCB and display unit to the front plate.} 
 
        The PCB is not allowed to be subjected to vibrations as it fastened to the front layer since the vibrating motor section is fixed to the back plate. At the joint of the back plate and the front layer vibrations can be damped out using rubber railing.

        \section{Overall size of the product}
        The overall size of the Metroband is an important factor to consider when designing it because it affects both the user experience and the technical aspects of the device. As it needs to be worn in hand, and signifies the tempo using vibrations, and as it needs to be easy to use and not interrupt the activity of playing an instrument the size of it becomes a constraint.\\
        
        To overcome the challenges associated with the size of the Metroband, we can use the following strategies:

        \begin{itemize}
            \item \textbf{Minimizing component size:}\\
            The size of the components used in the Metroband can be reduced as possible. Such as:
            \begin{compactitem}
                \item Smaller batteries (Polymer Battery 3.7V 150mAh 401530 Lithium Ion Battery)
                \item SMD components
                \item Coin vibrating motor 
            \end{compactitem}

            \item \textbf{Using compact designs:}\\
            The design can be compacted to make the most of the available space. This may involve using a square display to maximize screen space.

            \item \textbf{Prioritizing key features:}\\
            The key features that users are most likely to use can be prioritized and the design of the Metroband around those features is optimized. This may involve sacrificing some features or functionality to reduce the overall size of the device.
        \end{itemize}

\end{document}

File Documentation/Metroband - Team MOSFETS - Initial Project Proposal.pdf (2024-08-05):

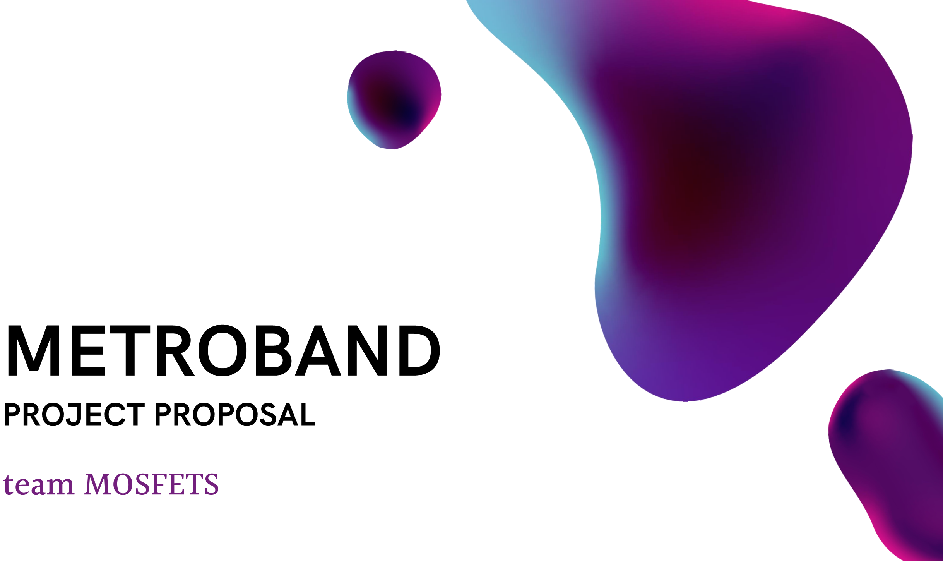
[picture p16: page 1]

# team MOSFETS

# The Problem, and the

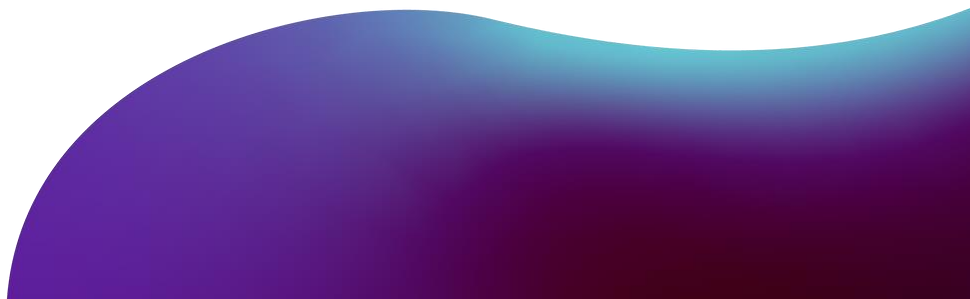
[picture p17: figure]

# Solution

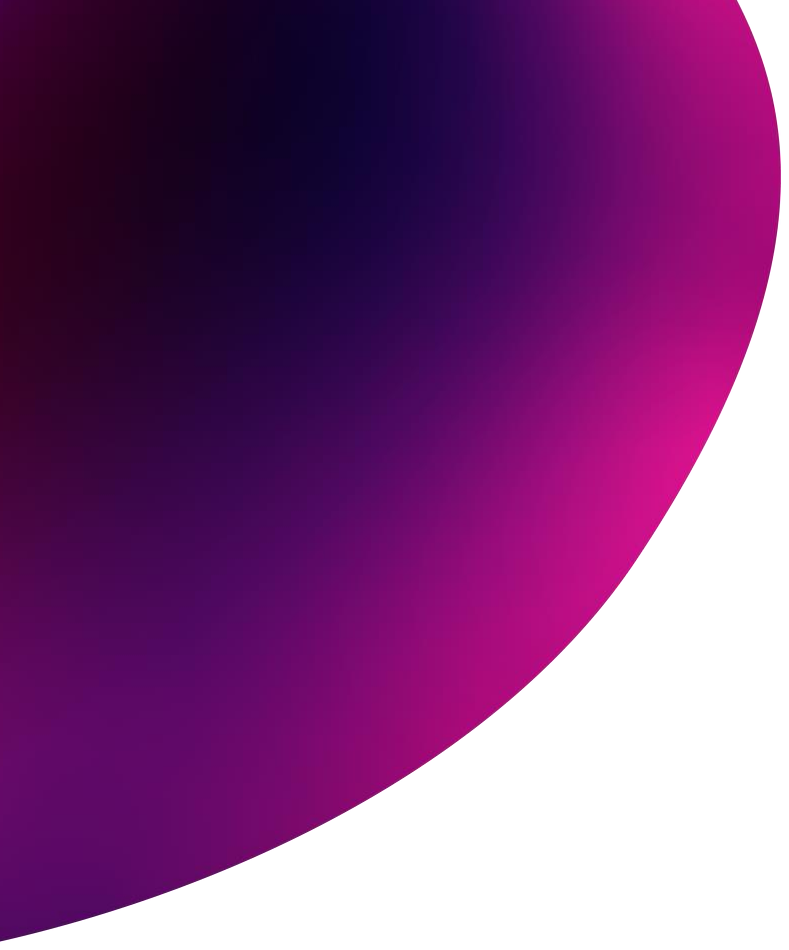
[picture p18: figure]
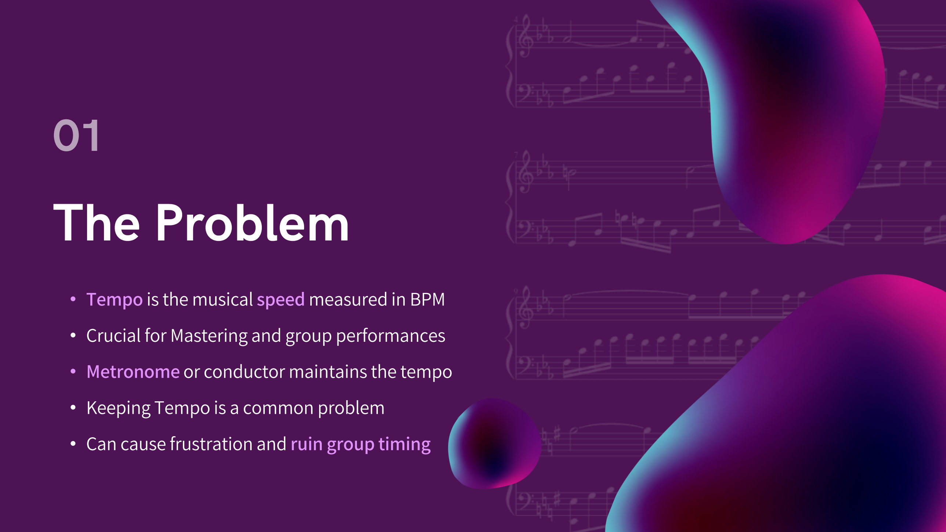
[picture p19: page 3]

## - Tempo is the musical speed measured in BPM - Crucial for Mastering and group performances - Metronome or conductor maintains the tempo - Keeping Tempo is a common problem - Can cause frustration and ruin group timing

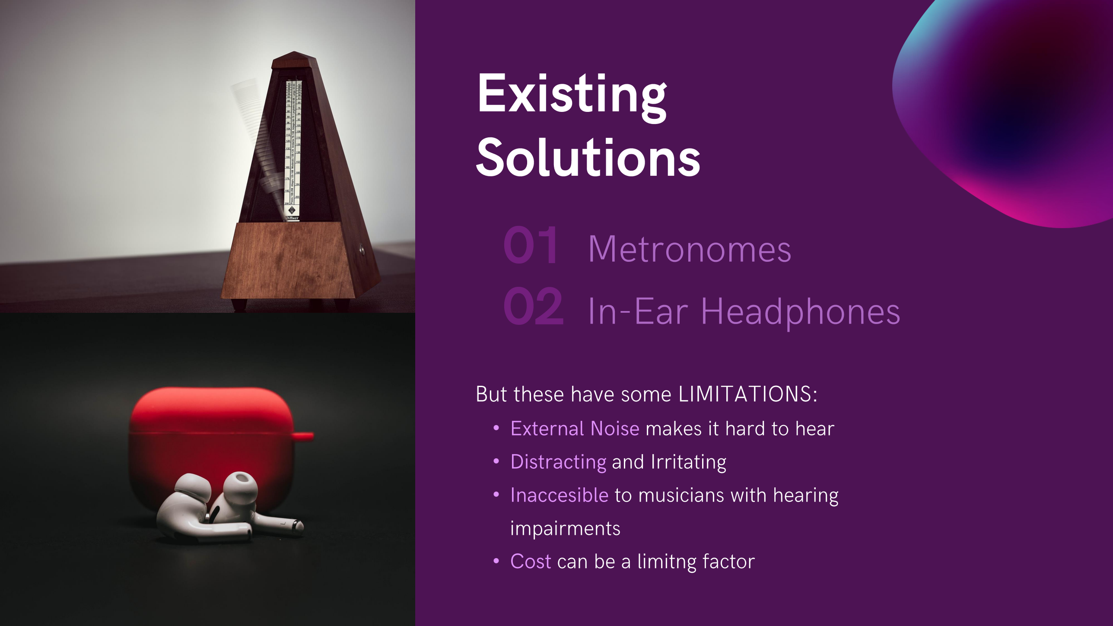
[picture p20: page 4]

••••

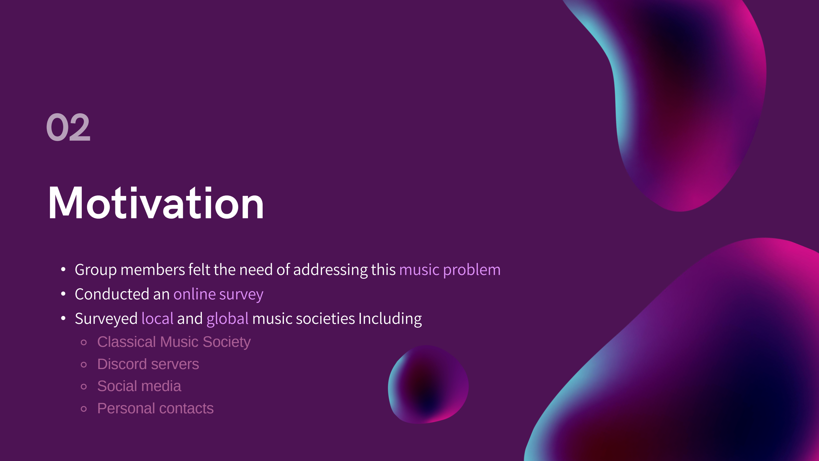
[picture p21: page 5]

## - Group members felt the need of addressing this music problem - Conducted an online survey - Surveyed local and global music societies Including

⚬ Classical Music Society
⚬ Discord servers
⚬ Social media
⚬ Personal contacts

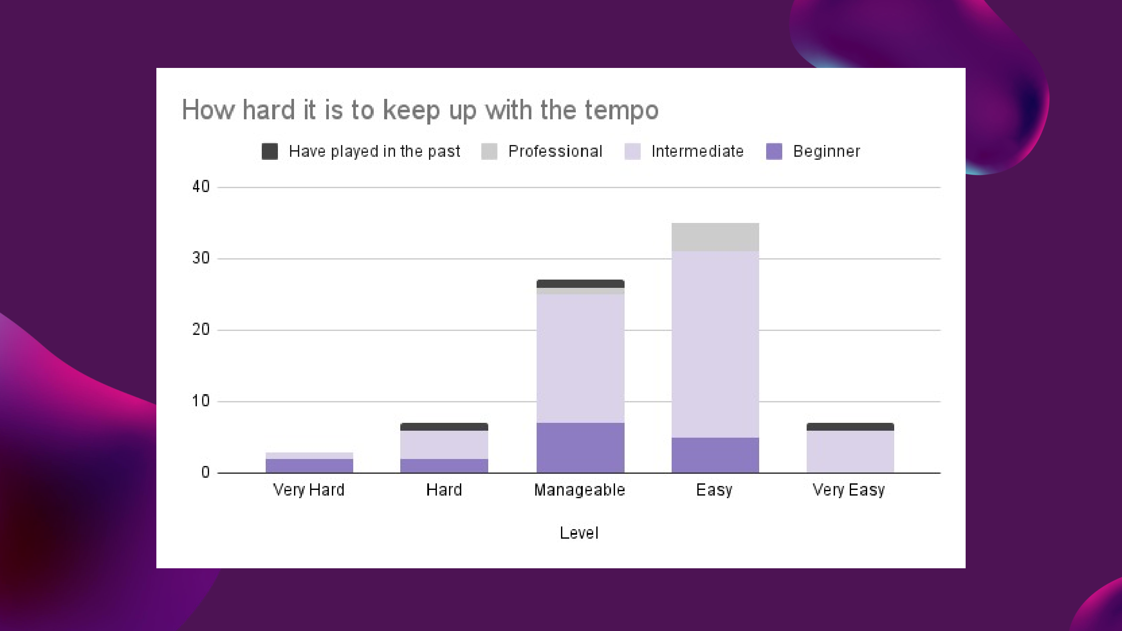
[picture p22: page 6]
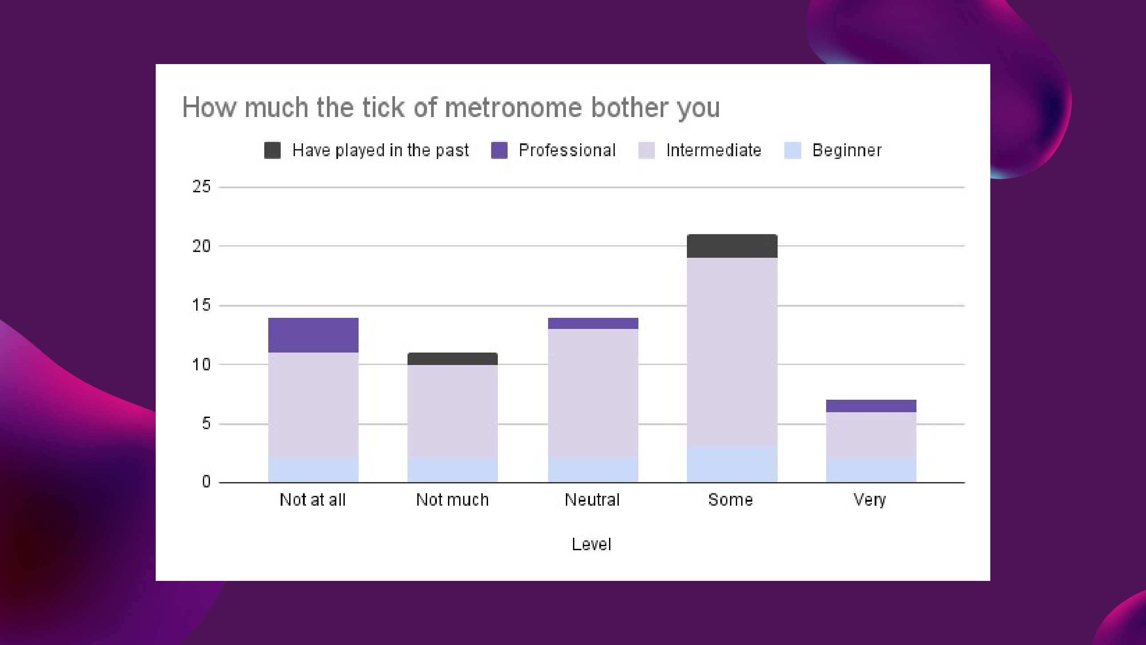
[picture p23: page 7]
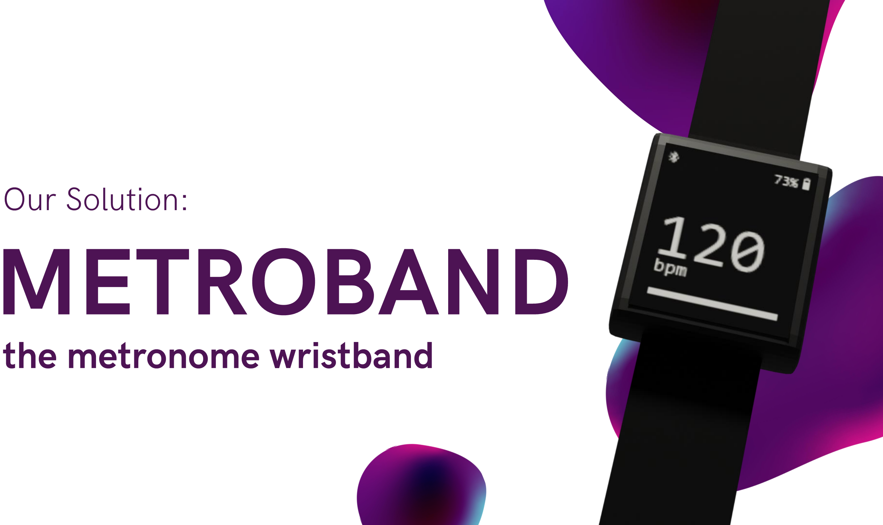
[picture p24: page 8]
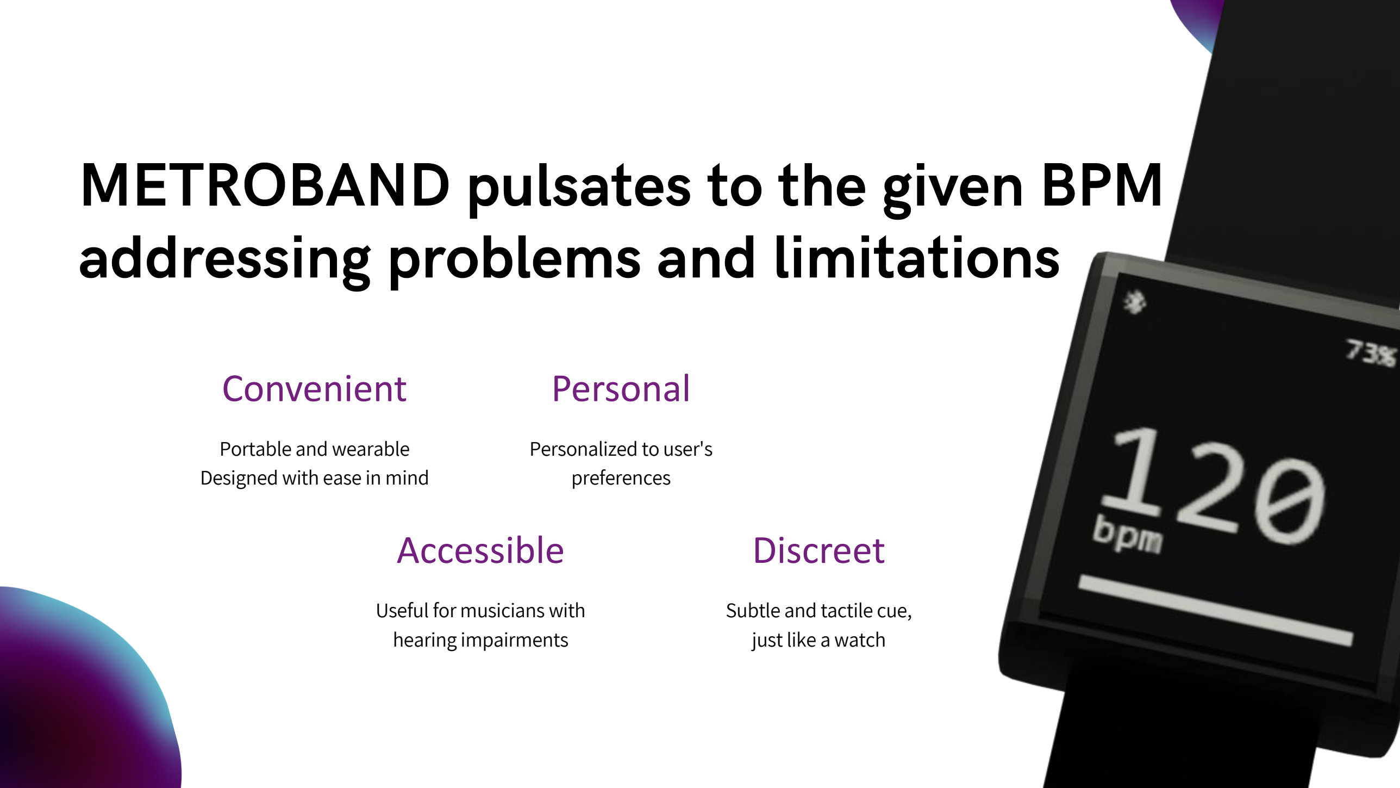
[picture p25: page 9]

## Convenient

Portable and wearable
Designed with ease in mind

## Personal

Personalized to user's
preferences

## Discreet

Subtle and tactile cue,
just like a watch

## Accessible

Useful for musicians with
hearing impairments


## - Metroband looks like a smartwatch - One knob for all operations - Dual-core microcontroller takes inputs - OLED display shows BPM

- Powered by a rechargeable Li-ion battery.


# Dual Core ESP32


We're using both the cores of the ESP32, one for time-keeping, and one for the other processes

## Bluetooth LTE


User can connect the their phone through the inbuilt Bluetooth functionality of ESP32

## OLED Display

Giving the user the experience of using a sleek experience of using an modern gadg


## - Added functionality of setting the BPM via bluetooth - Ability to set complex beat patterns - Ability to save presets


## Music Students

It would allow students and enthusiasts to practice music without loosing the feel to a tick

## Orchestras

It would help greatly for all the musicians in cutting down the time wasted on tempo


## Hearing Impaired

It would help the hearing
impaired people to enjoy the feeling of playing an instrument


### - Promotion via Social Media - Creative and informative videos - Focus: The mobile app, and syncing - Website

## Software


## Updates

The phone application will be constantly updated

## OTA Firmware Updates

More functionalities can be

added with the same hardware

## Recyclability

The product is mostly made of plastics and rubber, can be recycled at any service provider


### - Part by part simulated on Wokwi - Functionality and the sensing ability tested via an Arduino UNO


PCB Design
Power Module
Coding

Microcontroller
Enclosure
Market Research

Coding
PCB Design
Motor control

Enclosure
Mobile App
Budget Management


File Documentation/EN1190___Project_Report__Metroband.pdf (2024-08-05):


Department of Electronic & Telecommunication Engineering University of Moratuwa, Sri Lanka.

# Project Report: Metroband - The Metronome Wristband

team MOSFETS
210415N | Navarathne D.M.G.B.
210594J | Senevirathne I.U.B.
210608J | Silva L.J.J.P.
210609M | Silva M.K.Y.U.N.

Submitted in partial fulfillment of the requirements for the module EN 1190 Engineering Design Project

06/08/2024

Metroband - The Metronome Wristband | team MOSFETS

## Contents

1 Introduction | 2
2 Technical feasibility | 3
3 Product Architecture | 4
4 Sketches | 5
5 Finalized Project Details | 6
6 Project Budget | 9
7 Future Developments | 9
8 Marketing, Sales, and After-sales | 10
9 Task Allocation | 11

1

## 1 Introduction

The aim of this project is to design and develop a pulsating wristband according to a given BPM to give a better experience for beginner, intermediate or professional musicians. This project is undertaken by a team of four engineering undergraduates from the University of Moratuwa. The following report provides details of the progress made towards achieving the project objectives.

### 1.1 The Problem, and the Motivation to Solve it

### 1.1.1 Problem Definition

In music, BPM is the speed of a musical piece. It determines the overall energy and the feel of the musical performance. It is measured in Beats per Minute (BPM). In practicing to master a piece, it is crucial for one to be able to play it in time. This is even more important when playing in groups, where the whole group must play it at the same BPM. It is often maintained throughout the music using a metronome, in-ear headphones, or a conductor.

One of the major problems of musicians of both beginner and amateur levels, and sometimes even professionals is, keeping up the BPM while performing or practicing. For beginners, it brings great frustration as well as for many others when performing with a group it ruins the entire timing of the song. This often wastes a good fraction of the practice time.

There are a few solutions to combat this. Namely:
- Metronomes
- In-ear Headphones
But they too have their own potential problems and limitations which are listed below that have been complained about by many users:
- External noise: In noisy environments, metronomes can be hard to hear, and in-ear headphones can isolate the player from outside sounds, making it challenging to play with others.
- Distraction: Some musicians may find metronomes to be distracting or irritating, especially if they are practicing for extended periods of time. Over time, in-ear headphones may also result in ear discomfort or tiredness.
- Inaccessibility: Due to physical constraints or disabilities like hearing impairments, some musicians may find it challenging to utilize conventional metronomes or headphones, which have been recognized as a major issue.
- Cost: Metronomes and in-ear headphones can be expensive which will not make it feasible for many users.

### 1.1.2 Motivation for our solution

Since all our group members are practicing music up to some extent, we have all felt the need of addressing this problem. However, to gather more information about this matter we carried out an online survey which spanned out not only through local music societies but also across multiple global music societies as well. The communities from which we gathered information are as follows:
- Classical Music Society (CMS) of the University of Moratuwa
- Discord servers such as ‘We are engineers’ of Mattias Krantz and ‘RoomieOfficial’ of Joel Berghult; two popular Swedish music YouTubers
- Peer musician groups
- Social media such as X (formerly Twitter) and Facebook
- Personal contacts

2

The results of our survey are as follows:

Very Hard
Hard
Neutral

Easy
Very Easy

0

10

20

30

40

Categories

Values

Played in past | Beginner
Intermediate | Professional

Very Ineffective
Ineffective

Neutral

### Effective

Very Effective

0

10

20

Categories

Values

Played in past | Beginner
Intermediate | Professional

Figure 1: Comparison of Stacked Bar Charts A and B

### 1.2 Our Solution

As a solution to these critical problems and limitations that have arisen, after thorough observation and research, we have decided that the best solution would be a wristband that is pulsating according to a given BPM which we named ‘Metroband’. The reasonings for our solution are listed as follows:

- Convenience: A wristband is portable and wearable, so it can be used anywhere and anytime without the need for a separate device. This can be especially useful for musicians who need to maintain a consistent BPM while on the go, such as during rehearsals or performances.
- Discreetness: A vibrating wristband produces a subtle, tactile cue that only the wearer can feel, unlike a metronome which produces an audible sound that can be distracting or disruptive in certain settings, such as recording studios or quiet performance venues.
- Personalization: A wristband can be personalized to the user’s preferences, allowing them to set their own BPM and adjust the intensity of the vibrations to match their playing style or musical genre.
- Accessibility: A wristband can be a useful tool for musicians with hearing impairments or who prefer to play without auditory distractions, as it provides a non-auditory way to keep track of the BPM.

## 2 Technical feasibility

The physical appearance of the Metroband would be similar to a smartwatch which could be easily worn on the wrist with simply one knob to do all the operations. Moving onto the internal structure of the Metroband, it is basically built around a single dual-core microcontroller that takes inputs from the knob and displays the relevant BPM on an LCD display. All these devices are powered by

3

a rechargeable Lithium-Ion battery.

The required components such as ESP32, rotary encoders, LCD TFT displays, MCP73831 are readily available on the market, both on online vendors as well through local sellers. Further, thorough documentation of these components is available online.

We have planned on to programme the ESP32 using another ESP32 Development Kit, using the Arduino IDE. Due to the availability of well optimized free and open-source libraries, the implementation of Bluetooth can be done way far more efficiently.

## 3 Product Architecture

Below shown is a block diagram of the abstract modules in the Metroband. It has clearly mentioned the connections, data flow directions, and some data on what data are communicated between the modules that are described earlier.


Figure 2: Product architecture

Functionalities of each module is as follows:

### 3.1 ESP32 Micro-controller

This is the microcontroller that we will be using for our product. Each operation is split into tasks, and the ESP32 executes them according to the priority set by the code. Also, the Bluetooth module allows the device to communicate with the mobile app.

### 3.2 Switches

As the switch we are using a rotary encoder. Mainly because it can be used to many functionalities. By rotating it clockwise and counterclockwise, we can increase or decrease the BPM. By pressing and depressing it, we can play/pause sending pulses to the vibrating motor. Long press will switch on/off the devices.

4

### 3.3 LCD TFT Display

This will be the display used to mainly show the BPM. Other than that, it will show the Bluetooth connectivity and battery percentage as well.

### 3.4 Coin Vibrator

This is the vibrating motor used in our device. It vibrates according to the pulses sent by the microcontroller. In fact, the pulses will be sent through a transistor in switch mode which will give the full power of the battery to the motor.

### 3.5 Power

We will be using a rechargeable Lithium-Ion battery to power up all the devices in our product. To handle the charging process, there will be charging IC as well.

## 4 Sketches

### 4.1 Initial Sketches


Figure 3: Initial sketch

5


### 4.2 Final Design

Figure 4: Final design, worn on hand

## 5 Finalized Project Details

### 5.1 Schematic and PCB

Figure 5: Schematic Diagram

The circuit diagram of the product is shown below in Figure 5. It was designed with a voltage regulator as the battery gives a voltage of 4.2V when fully charged, and the ESP32 requires 3.6-2.2V. Although the IC was included in the circuit, due to predictions of local unavailability of the ICs we included a slot for a zener diode of 3.3V to be soldered as well.

Several modifications were done for the display, as we chose a TFT display rather than an OLED display.

6


Figure 6: PCB overview

Figure 7: 3D view of the PCB

All the functionalities of the circuit are controlled by the rotary encoder and its inbuilt pushbutton (manually) and via bluetooth.

7

The PCB in size is 42.5mm x 38mm as it requires to be small enough to fit on a wrist. Hence it was required to use SMD components. also the required clearances for the antenna of the ESP32 were kept. ESP32 was planned to be programmed with the UART converter of a development board, and for this purpose several test pads were kept so wires could be soldered and it desoldered at the last minute.

### 5.2 Coding

For coding we used the ESP IDF. We carried out the tasks separately in the singular core rather than carrying all the tasks in a singular loop while adjusting their priorities. Also we had to use multiple libraries in order to code the parts related to bluetooth, display and other functions of the ESP32. Further, we had to design the bitmap of the icons as well as the numbers, as we used a 16-segment display font.

### 5.3 Enclosure Design

The enclosure was designed using SOLIDWORKS 2023.We needed to get the enclosure as detailed as possible with minimum dimensions.


Figure 8: Enclosure SOLIDWORKS design

8

## 6 Project Budget

Item | Quantity | Unit Price | Price
Coin vibrator Battery TFT display unit Regulator IC Fuel gauge IC Charger IC mini USB slot PCB Design and Printing Enclosure Printing Padding and Straps Resistors Capacitors Transistor Esp 32 module Rotary Encoder | 1 1 1 1 1 1 1 ---6 8 1 1 1 | RS.300 Rs.450 Rs.1400 Rs.185 Rs.500 Rs.350 Rs.150 -----Rs.5 Rs.700 Rs.350 | RS.300 Rs.450 Rs.1400 Rs.185 Rs.500 Rs.350 Rs.150 Rs.500 Rs.760 Rs.250 Rs.50 Rs.50 Rs.5 Rs.700 Rs.350
Total cost for components Number of units Marketing and sales cost Profit per unit Product price | ----- | ----- | Rs.5995.00 200 Rs.10,000 Rs.5000 Rs.10,000

## 7 Future Developments

### 7.1 Size

Currently we have identified that the size of the prototype could be a hindrance for some musicians. Hence we intend to reduce the size of the watch to a wearable size. In order to do this we have come across few methods:

- Using a TFT display without the breakout PCB, as the PCB and the pin headers add 3 mm to the height
- By using a smaller rotary encoder which is usually used in applications such as smartwatches, we can further reduce the height
- By resorting to a further compact design in designing the PCB, and outsourcing the soldering of components to a ‘pick and place’ services provider, the length and width of the apparatus could be reduced
- By choosing a thinner battery, the height could be further reduced

### 7.2 Display

Currently we have included a 1.44 inch TFT. As this does not cover the complete front face of the watch, we have identified that it would be better to choose a display slightly larger than the current display, which would be rather aesthetically pleasing to the consumer.
Further, the current display elements are designed in such a way so they are reminiscent of the classic ‘Vacuum Fluorescent Displays’, which would be further improved in the design phase to further resemble.

9

### 7.3 Vibration Intensity

For musicians who play rather delicate instruments such as piano or violin, more subtle vibrations are required. And some users would need a user set vibration intensity for the device to vibrate with. For this, we have identified using a PWM signal with an adjustable duty cycle as a solution. The code will be changed accordingly to achieve this, and a setting to change the intensity would be added to the mobile app.

### 7.4 USB C port

Recently, USB-C has become the standard connector for the devices. Hence USB-C cables are becoming more available. Hence by changing the Micro-USB to a USB-C port, we give the consumer the opportunity to use any charging cable as they would please.

### 7.5 Battery

With the current battery, the device’s charge remains up to 5 hours when in use. This could be further improved with using a battery with a better capacity, while retaining (or preferably reducing) the size.

### 7.6 Enclosure

The enclosure will have a design makeover, with a newer, more attractive design which suits the modern market. The straps would be replaced with more comfortable silicone straps, and the body would have a more sleek design.

### 7.7 Mobile Application

The app is to be featured with additional features. The vibration intensity can be set by the mobile app which will make it feasible for playing different instruments that require different vibration intensities. Moreover, presets can be saved in the mobile app so that the Metroband can help the musicians in playing music that changes its beat in-between or gradually. Additionally, playlists can be saved in the mobile app. Also the UI design will be improved.

## 8 Marketing, Sales, and After-sales

### 8.1 Marketing

We’ll be focusing our marketing effort on musicians, music students, choirs and orchestras. The silent and convenient alternative to traditional metronomes, allowing for uninterrupted practice sessions will be highlighted which will be offered by the “Metroband”.

We’ll be engaging with online communities, forums, Facebook, WhatsApp, twitter and other social media groups that are dedicated to musicians and music enthusiasts. We will be participating in discussions, sharing valuable insights while promoting the “Metroband” as a useful tool not only for the musicians seeking an innovative way to keep the BPM without the noise, but also for the musicians with hearing disorders to keep up their beat in time.

We’ll be also creating engaging creative videos that demonstrate the functionality, the benefits and the need of the “Metroband” for the musicians. Moreover, how the wristband can be synchronized with various instruments and used during practice sessions can be shown. These videos will be shared on our website and social media platforms.

10

Also we were able to present our product at the EXMO exhibition which was held on 27th to 29th of July, which gave a great exposure for our product, which also gave us the opportunity to connect with potential investors.

### 8.2 After-sales

Encourage the customers to provide feedback and testimonials about their experience using the “Metroband”. Positive reviews can be highlighted and posted on social media channels to gain the trust and attract new customers. Negative reviews will be carefully comprehended, and prompt actions will be taken to resolve them.

Because the ESP32 board is used here we are able to code it so that it is able to receive over the air firmware updates (OTA updates). Because of this even more functionalities can be added even after the sale of the product.

The product’s disposability is also taken into consideration. There will be detailed instructions on how to properly dispose of the wristbands, including details on recycling possibilities. Any harmful or poisonous materials can be reused or given to electronic shops for reuse because they are not used in the electronic component. Additionally, details will be provided on how customers can return straps so that we can recycle or re-purpose them.

## 9 Task Allocation

- Nawarathna D.M.G.B

– Coding

– PCB Design

– Vibrating Motor Module

- Senevirathne I.U.B

– OLED Display Module

– Web App Development

– Budget Management

– Enclosure Design

- Silva L.J.J.P

– Microcontroller and the Peripherals

– Enclosure Design

– Market Research

- Silva M.K.Y.U.N

– PCB Design

– Schematic

– Fuel Gauge

– Coding

11

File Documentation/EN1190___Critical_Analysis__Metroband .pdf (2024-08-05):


Department of Electronic & Telecommunication Engineering University of Moratuwa, Sri Lanka.

# Critical Analysis: Metroband

team MOSFETS
210415N | Navarathne D.M.G.B.
210594J | Senevirathne I.U.B.
210608J | Silva L.J.J.P.
210609M | Silva M.K.Y.U.N.

Submitted in partial fulfillment of the requirements for the module EN 1190 Engineering Design Project

08/05/2024

Metroband - The Metronome Wristband | team MOSFETS

The following report provides a critical analysis of the project for the design and development of the Metroband. The project aims to create a wristband that can pulse in sync with the tempo, providing a novel and engaging user experience. The design incorporates a microcontroller, a vibrating motor, and a display unit, all housed in a compact and comfortable wristband. The purpose of this report is to evaluate the success of the project in meeting its goals, as well as to identify any areas for improvement or further development.

Below mentioned are the probable constraints and the suggested solutions to overcome:

## 1 Battery life

DC motors usually draw some more current than other components, specifically in the start of the rotation. Vibrator is something having a similar mechanism to a motor, and in giving the tempo it would have to start up the rotation several times corresponding to the Beats per Minute value. Hence it might draw a larger current, which might not be a good thing for some components, as well as drain the batteries quicker.

This can be overcome by using the following strategies.

### 1.1 Using Low power Bluetooth - built-in Bluetooth Low Energy chip in

ESP32


Why the built-in Bluetooth Low Energy chip in ESP32?
- Low power consumption:
Bluetooth Low Energy is designed to be highly energy-efficient, allowing devices to operate on a small battery for long periods of time. This makes it the best suited communication protocol for low-power devices like the ESP32.
- Short-range communication:
BLE is designed for short-range communication, which means that it is ideal for use in the “Metroband”.
- Compatibility:
BLE is widely adopted and supported by most modern smartphones, making it easy to communicate with a wide range of devices.
- Easy to use:
Can easily add wireless communication to the project without the need for additional hardware because of the built-in BLE chip.

1

Related problems and the solutions:

- Interference:
BLE operates in the same frequency band as other wireless devices, which means that it may be subject to interference from other wireless signals. But the frequency ranges that are probable in concerts and bands do not belong to the range of the BLE frequency range. Also, Bluetooth is used in this device to send a unit pulse which will not be much affected by the other signals. For example:

– Wireless Microphones: 516-558 MHz

– In-Ear Monitors: 470-952 MHz

– Wireless Intercom Systems: 470-698 MHz

- Complexity: BLE can be more complex to implement than other wireless communication protocols but due to in built libraries in ESP 32 Bluetooth module can be accessed easily.

### 1.2 Better battery - Polymer 3.7V 150mAh 401530 Lithium Ion Battery


Why Polymer 3.7V 150mAh 401530 Lithium Ion Battery?

- High energy density:
Polymer batteries have a higher energy density than other types of batteries, meaning they can store more energy per unit of volume, allowing for longer battery life in a small form factor.
- Low self-discharge rate:
Polymer batteries have a lower self-discharge rate than other types of batteries, meaning they can hold their charge for longer periods without losing significant energy.
- Lightweight and compact:
Polymer batteries are very lightweight and can be molded into various shapes and sizes, making them an ideal choice for small wearable devices like smartwatches.

Related problems and the solutions:

- Limited lifespan and Vulnerable to high temperatures:
One solution to prolong the lifespan of the polymer battery is to avoid exposing it to high temperatures, which can cause the battery to degrade faster.
Moreover, Heats pads and ventilating slots in the enclosure can be designed to overcome the above issues. Additionally, using the correct charging method and avoiding overcharging or discharging the battery can help extend its lifespan.

2

- Risk of overcharging:
To avoid overcharging the battery a TP4056 - SOIC8 - Li-on Battery Charger IC 1A is used(https://www.sunrom.com/p/tp4056-li-on-battery-charger-ic-1a). It helps prevent overcharging by using a constant-current charging method, including built-in overcharging protection, and an auto-termination feature. This helps ensure that the battery is charged safely and optimally, without the risk of overcharging.


- Output voltage from the IC is not enough to drive the motor:
Output from the GPIO pins of the module can give only 40 mA when the vibration motor requires 75 mA to run, which means to start it requires an even larger current. Since connecting the motor directly to module can damage the module as well as it might result in motor not starting up at certain orientation. As a solution for this we can give the output from the module to the base of a transistor and use it as a switch.

## 2 Timing

Singular core micro controller processes sequentially, but in the Metroband as we need certain tasks to be done simultaneously, we are restricted from achieving this. Moreover, it affects the processing speed as a single-core microcontroller may not be able to process data leading to slower response times and potential inaccuracies in measuring the user’s BPM. Furthermore, the functionality also becomes limited as a single-core microcontroller may not have the necessary resources to handle complex algorithms or multiple inputs and outputs.

But there is a trade off in using multicores as the power consumption increases with the increasing number of cores.

These issues can be overcome by:

### 2.1 Using a Dual core microcontroller - ESP-32S WiFi Bluetooth Dual

Mode Module (MD0271)

Why ESP-32S WiFi Bluetooth Dual Mode Module (MD0271)

- Improved performance:
With two cores, the microcontroller can handle multiple tasks simultaneously, improving the overall performance of the wristband.
- More functionality:
This microcontroller can handle more complex algorithms, multiple inputs, and outputs, enabling the Metroband to perform more functions than a single-core microcontroller.

3

- Enhanced responsiveness:


With multiple cores, the wristband can more quickly respond to user inputs or changes in BPM, improving overall user experience.

## 3 Vibrations

The device gives the tempo with vibrations, and since all the components need to be packed into a small compartment, other components including the PCB would constantly be subjected to vibrations. And these vibrations cannot be made less intense as that would mean it would be harder for the user to sense the vibrations.

These issues can overcome by using these strategies:

### 3.1 Using High Density Polyethylene/ polypropylene or Acrylonitrile Bu-

tadiene Styrene for the back plate.

Why High-Density Polyethylene/ polypropylene or Acrylonitrile Butadiene Styrene?

- Feels vibrations more effectively:
User feels vibrations more effectively because of their unique properties.
- Durability:
HDPE, PP, and ABS are all known for their toughness and durability. They are resistant to impact, abrasion, and chemicals, making them ideal for use in a wristband that may be exposed to rough conditions or frequent use.
- Lightweight:
HDPE, PP, and ABS are all lightweight materials, which can help keep the overall weight of the wristband low and comfortable to wear.
- Cost-effective:
These materials are relatively inexpensive compared to other materials such as metals or composites, which can help keep the overall cost of manufacturing the wristband low.

### 3.2 Separate the vibrating motor and the PCB with butyl rubber:

- Vibration isolation:
Butyl rubber is a good vibration-damping material, which means that it can absorb and dampen the vibrations produced by the motor. By isolating the motor from the PCB with butyl rubber, the vibrations are less likely to affect the electronic components on the PCB, which can help improve the reliability and longevity of the wristband.

4

- Shock absorption:
In addition to absorbing vibrations, butyl rubber can also absorb shocks and impacts, which can be important in a wristband that may be subjected to rough handling or impacts.
- Noise reduction:
By absorbing and damping the vibrations produced by the motor, butyl rubber can also help reduce the amount of noise generated by the motor, which can improve the overall user experience.

### 3.3 Vibration motor section can be fixed to the back plate and PCB and

display unit to the front plate.

The PCB is not allowed to be subjected to vibrations as it fastened to the front layer since the vibrating motor section is fixed to the back plate. At the joint of the back plate and the front layer vibrations can be damped out using rubber railing.

## 4 Overall size of the product

The overall size of the Metroband is an important factor to consider when designing it because it affects both the user experience and the technical aspects of the device. As it needs to be worn in hand, and signifies the tempo using vibrations, and as it needs to be easy to use and not interrupt the activity of playing an instrument the size of it becomes a constraint.

To overcome the challenges associated with the size of the Metroband, we can use the following strategies:

- Minimizing component size:
The size of the components used in the Metroband can be reduced as possible. Such as: – Smaller batteries (Polymer Battery 3.7V 150mAh 401530 Lithium Ion Battery)
– SMD components
– Coin vibrating motor
- Using compact designs:
The design can be compacted to make the most of the available space. This may involve using a square display to maximize screen space.
- Prioritizing key features:
The key features that users are most likely to use can be prioritized and the design of the Metroband around those features is optimized. This may involve sacrificing some features or functionality to reduce the overall size of the device.

5

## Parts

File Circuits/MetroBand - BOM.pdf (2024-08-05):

Description | Designator | Quantity
Fixed Positive LDO Regulator, 3.3V, 0.9V Dropout, CMOS, PDSO8 | U1 | 1
IC 2-WIRE FG MODEL GAUGE LO BATT | U2 | 1
IC CONTROLLR LI-ION 4.2V SOT23-5 | U3 | 1
Male Shrouded Header WR-WTB, SMT, Right Angled, pitch 2 mm, 1 x 2 position | P1 | 1
Micro-USB B Receptacle, Right Angle, Bottom Mount, Surface Mount, with Solder Tabs, -30 to 85 degC, 5-Pin USB, RoHS, Tape and Reel | J1 | 1
ROTARY ENCODER MECHANICAL 12PPR | ENC1 | 1
Schottky Barrier Diode, 2-Pin SOD-323, Pb-Free, Tape and Reel | D2 | 1
Switching Transistor, PNP Silicon, 3-Pin SOT-23, Pb-Free, Tape and Reel | Q2 | 1
THT Vertical Pin Header WR-PHD, Pitch 2.54 mm, Single Row, 2 pins | P3 | 1
THT Vertical Pin Header WR-PHD, Pitch 2.54 mm, Single Row, 8 pins | P2 | 1
TRANSISTOR, NPN, REEL 3K | Q1 | 1
WIFI MODULE 32MBITS SPI FLASH | MD1 | 1
Zener Voltage Regulator, 500 mW, 2-Pin SOD-523, Pb-Free, Tape and Reel | D1 | 1
Chip Multilayer Ceramic Capacitors for General Purpose, 0805, 10uF, X5R, 15%, 10%, 25V | C1, C2, C3, C4, C5, C6, C7, C8, C9 | 9
Wirepad | PAD1, PAD2, PAD3, PAD4, PAD5, PAD6, PAD7, PAD8, PAD9, PAD10, PAD11 | 11
Chip Resistor, 0 Ohm, Jumper, 100 mW, -55 to 155 degC, 0603 (1608 Metric), RoHS, Tape and Reel | R1, R2, R3, R4, R5, R6, R7, R8, R9, R10, R11, R12, R13, R14, R15, R16, R17 | 17

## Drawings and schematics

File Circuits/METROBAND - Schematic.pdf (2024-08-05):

1 2 3

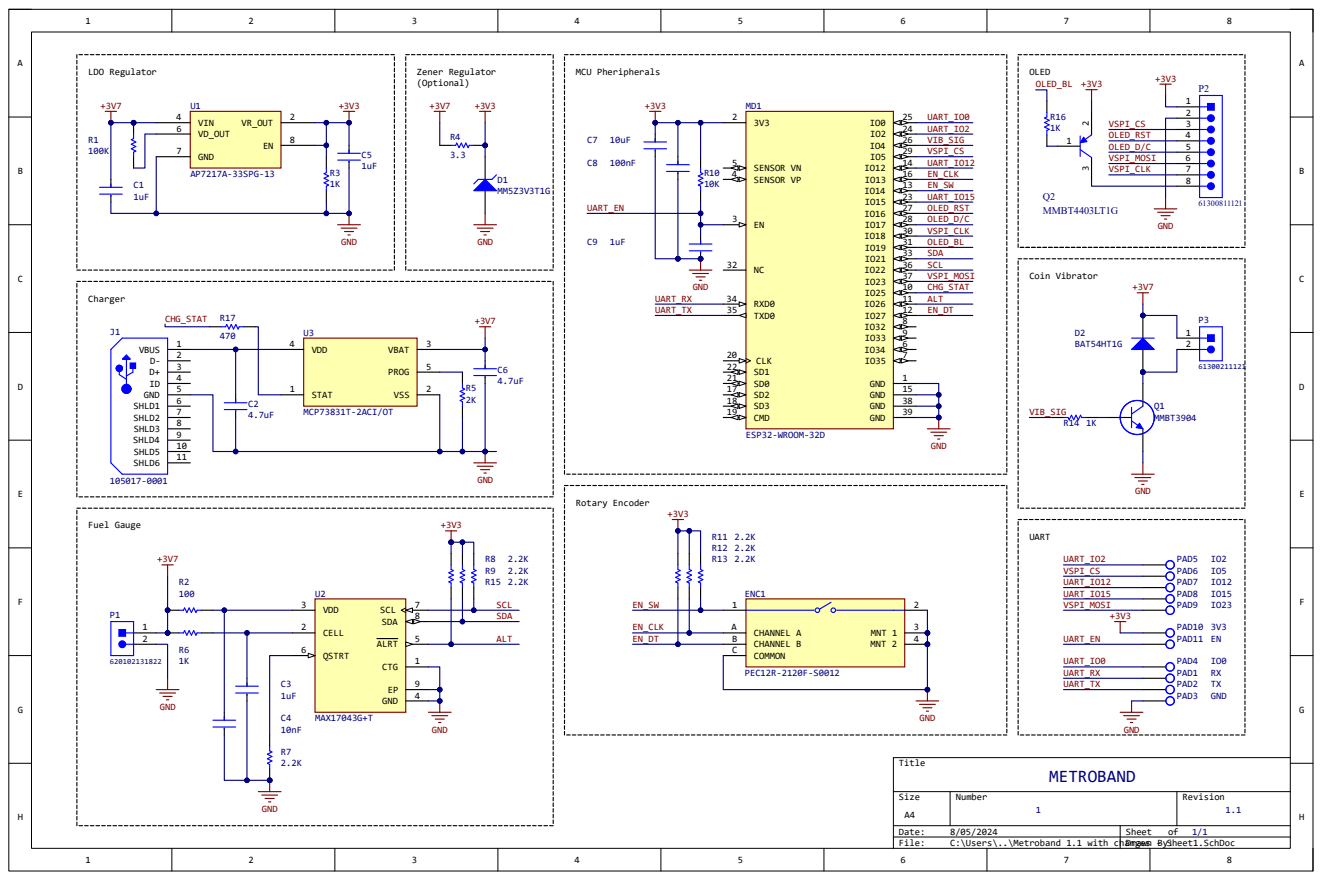
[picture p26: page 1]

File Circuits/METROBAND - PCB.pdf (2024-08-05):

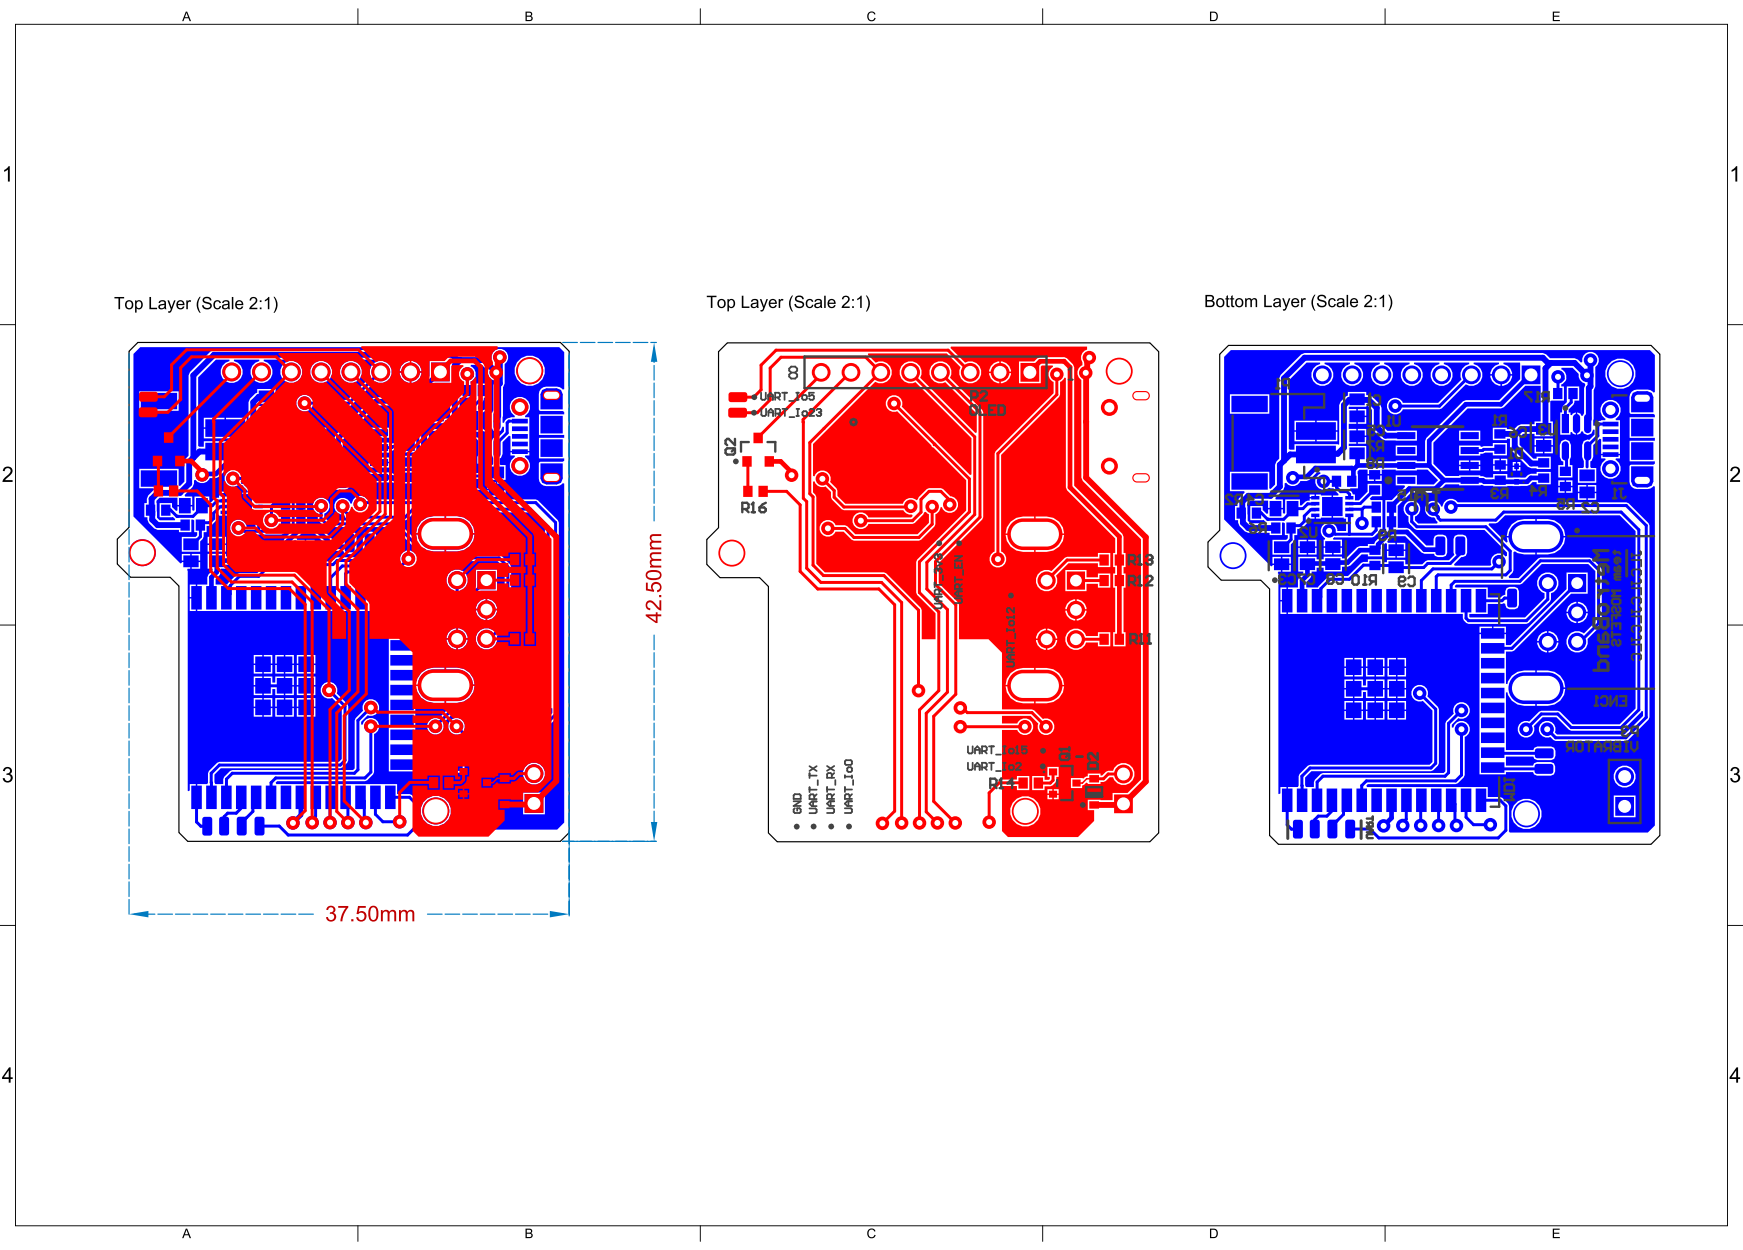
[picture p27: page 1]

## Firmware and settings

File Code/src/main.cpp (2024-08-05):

#include <Arduino.h>
#include <TFT_eSPI.h>
#include <SPI.h>
#include "BluetoothSerial.h"

// fonts, icons
#include "dec14.h"
#include "icons.h"


String blue_text = ""; //bluetooth message
int coin = 0;
int motstat = 0;
int blstat = 1;

#if !defined(CONFIG_BT_ENABLED) || !defined(CONFIG_BLUEDROID_ENABLED)
#error Bluetooth is not enabled! Please run `make menuconfig` to and enable it
#endif

BluetoothSerial SerialBT;

TFT_eSPI tft = TFT_eSPI();  // Invoke Library

#define chgsense 12 // lets know if the watch is charging (connect to CHG_STAT
                    // from MCP7383

// Rotary encoder:
// Interchange ROT_DT and ROT_CL to invert the direction of increment 
#define ROT_SW 14
#define ROT_DT 27
#define ROT_CL 13  

#define MOT_OUT 19

TaskHandle_t Task1;
TaskHandle_t Task2;
TaskHandle_t Task3;

void setup() {
  // put your setup code here, to run once:
  Serial.begin(115200);
  SerialBT.begin("MetroBand"); //Bluetooth device name
  tft.init();
  tft.fillScreen(TFT_BLACK);
  tft.setTextColor(TFT_WHITE, TFT_BLACK);

  pinMode(ROT_SW, INPUT);
  pinMode(ROT_DT, INPUT);
  pinMode(ROT_CL, INPUT);
  pinMode(MOT_OUT, OUTPUT);

  pinMode(22, OUTPUT);
  digitalWrite(22,HIGH);
  wordtrain("- METROBAND -",300);


  // Tasks
  xTaskCreatePinnedToCore(
                    Task1code,   /* Task function. */
                    "Task1",     /* name of task. */
                    10000,       /* Stack size of task */
                    NULL,        /* parameter of the task */
                    1,           /* priority of the task */
                    &Task1,      /* Task handle to keep track of created task */
                    1);          /* pin task to core 1 */                  
  delay(500);

  xTaskCreatePinnedToCore(
                    Task2code,   /* Task function. */
                    "Task2",     /* name of task. */
                    10000,       /* Stack size of task */
                    NULL,        /* parameter of the task */
                    1,           /* priority of the task */
                    &Task2,      /* Task handle to keep track of created task */
                    1);          /* pin task to core 0 */         //(0)
    delay(500);

  xTaskCreatePinnedToCore(
                    Task3code,   /* Task function. */
                    "Task3",     /* name of task. */
                    10000,       /* Stack size of task */
                    NULL,        /* parameter of the task */
                    1,           /* priority of the task */     //(2)
                    &Task3,      /* Task handle to keep track of created task */
                    1);          /* pin task to core 1 */
    delay(500);
}


int lastClk = HIGH;
int BPM = 100;
float HIGH_T = 0.1;
float LOW_T = 0.0;


//Task1code: Calculating BPM and other tasks
void Task1code( void * pvParameters ){
  for(;;){

    if (SerialBT.available() > 0) {
      blue_text = SerialBT.readStringUntil('\n');
      if(blue_text.toInt() != 0){
        BPM = blue_text.toInt();
      } else {
        coin = 1;
      }
    }
  
    int newClk = digitalRead(ROT_CL);

    if (newClk != lastClk) {
      // There was a change on the CLK pin
      lastClk = newClk;
      int dtValue = digitalRead(ROT_DT);

      if (newClk == LOW && dtValue == HIGH) {
        BPM += 1;
      }
      if (newClk == LOW && dtValue == LOW) {
        BPM -= 1;
      }
    }
    LOW_T = 60.0/BPM - HIGH_T;
  }
}


//Task2code: blinks the LED to the given BPM
void Task2code( void * pvParameters ){

  for(;;){
    if(digitalRead(ROT_SW)==LOW || coin == 1) {
    coin = 0;
    motstat = 1;
    for (;;) {
      digitalWrite(MOT_OUT, HIGH);
      delay(HIGH_T*1000);
      digitalWrite(MOT_OUT, LOW);
      delay(LOW_T*1000);
      if(digitalRead(ROT_SW)==LOW || coin == 1) {
        coin = 0;
        motstat = 0;
        break;
      }
    }
    delay(1000);
    }
  }
}

//Task3code: display
void Task3code(void * pvParameters){
  for(;;){
    tft.fillScreen(TFT_BLACK);
    tft.setTextColor(TFT_WHITE);

    float voltage  = 2096*3.3/4095;   //analogread(34)
    int percentage = round(voltage/3.3*100);

    String BPMtxt;
    if (BPM>=100){
      BPMtxt = String(BPM);
    } else if (BPM>=10){
      BPMtxt = " " + String(BPM);
    } else {
      BPMtxt = "  " + String(BPM);
    }

    if (motstat==0) {
      tft.drawBitmap(6,18,ch_ps,50,13,TFT_CYAN);
    } else {
      tft.drawBitmap(6,33,ch_pl,50,13,TFT_YELLOW);
    }

    bignum(BPMtxt);

    tft.setTextColor(TFT_BLACK,TFT_RED);
    tft.fillRect(78, 108, 42, 20, TFT_RED);
    tft.fillTriangle(71, 108, 78, 108, 78, 128, TFT_RED);
    displayPrint("BPM",82, 111, 2); //83,74
    tft.setTextColor(TFT_WHITE);

    if (blstat==0){
      tft.drawBitmap(0,0,ch_btsc,33,15,TFT_CYAN);
    } else {
      tft.drawBitmap(0,0,ch_btsc,33,15,TFT_CYAN);
    }
    int right = 128;
    if (digitalRead(chgsense)) {
      right -= 10;
      tft.drawBitmap(51,0,ch_chg,12,15,TFT_CYAN);
    }
    if (percentage>75) {
      tft.drawBitmap(98,0,ch_b100,30,15,TFT_CYAN);
    } else if (percentage>50) {
      tft.drawBitmap(98,0,ch_b75,30,15,TFT_CYAN);
    } else if (percentage>25) {
      tft.drawBitmap(98,0,ch_b50,30,15,TFT_CYAN);
    } else {
      tft.drawBitmap(98,0,ch_b25,30,15,TFT_CYAN);
    }
    int col = 70;
    if (percentage==100) {
      col -= 6;
    } else if (percentage<10) {
      col += 6;
    }
    tft.setTextColor(TFT_CYAN);
    displayPrint((String(percentage)+"%"),col, 4, 1);
    tft.setTextColor(TFT_WHITE);

    delay(1000); 
  }
}

void loop() {}

// Dipslays text on TFT
void displayPrint(String text,int column,int row,int size){
  tft.setCursor(column, row); // (column, row)
  tft.setTextSize(size);
  tft.println(text);
}

// Displays on main 14seg 
void bignum(String bignumtxt){
  int vfd = 30;
  tft.drawBitmap( 3,60,bn_ALL,39,42,tft.color565(vfd,vfd,vfd));
  tft.drawBitmap(42,60,bn_ALL,39,42,tft.color565(vfd,vfd,vfd));
  tft.drawBitmap(81,60,bn_ALL,39,42,tft.color565(vfd,vfd,vfd));

  char bigArray[3];
  bignumtxt.toCharArray(bigArray, bignumtxt.length()+1);

  charcall(bigArray[0],0);
  charcall(bigArray[1],1);
  charcall(bigArray[2],2);
}

//Sorts char from libraries
void charcall(char letter, int pos){
  int posx;
  if (pos==0) {
    posx = 3;
  } else if (pos==1) {
    posx = 42;
  } else if (pos==2) {
    posx = 81;
  }

  int posy = 60;

  if (letter==48) {
    tft.drawBitmap(posx,posy,bn_0,39,42,TFT_WHITE); //0
  } else if (letter==49) {
    tft.drawBitmap(posx,posy,bn_1,39,42,TFT_WHITE); //1
  } else if (letter==50) {
    tft.drawBitmap(posx,posy,bn_2,39,42,TFT_WHITE); //2
  } else if (letter==51) {
    tft.drawBitmap(posx,posy,bn_3,39,42,TFT_WHITE); //3
  } else if (letter==52) {
    tft.drawBitmap(posx,posy,bn_4,39,42,TFT_WHITE); //4
  } else if (letter==53) {
    tft.drawBitmap(posx,posy,bn_5,39,42,TFT_WHITE); //5
  } else if (letter==54) {
    tft.drawBitmap(posx,posy,bn_6,39,42,TFT_WHITE); //6
  } else if (letter==55) {
    tft.drawBitmap(posx,posy,bn_7,39,42,TFT_WHITE); //7
  } else if (letter==56) {
    tft.drawBitmap(posx,posy,bn_8,39,42,TFT_WHITE); //8
  } else if (letter==57) {
    tft.drawBitmap(posx,posy,bn_9,39,42,TFT_WHITE); //9
  } else if (letter==84) {
    tft.drawBitmap(posx,posy,bn_T,39,42,TFT_WHITE); //T
  } else if (letter==69) {
    tft.drawBitmap(posx,posy,bn_E,39,42,TFT_WHITE); //E
  } else if (letter==66) {
    tft.drawBitmap(posx,posy,bn_B,39,42,TFT_WHITE); //B
  } else if (letter==79) {
    tft.drawBitmap(posx,posy,bn_O,39,42,TFT_WHITE); //O
  } else if (letter==78) {
    tft.drawBitmap(posx,posy,bn_N,39,42,TFT_WHITE); //N
  } else if (letter==45) {
    tft.drawBitmap(posx,posy,bn__,39,42,TFT_WHITE); //-
  } else if (letter==65) {
    tft.drawBitmap(posx,posy,bn_A,39,42,TFT_WHITE); //A
  } else if (letter==82) {
    tft.drawBitmap(posx,posy,bn_R,39,42,TFT_WHITE); //R
  } else if (letter==68) {
    tft.drawBitmap(posx,posy,bn_D,39,42,TFT_WHITE); //D
  } else if (letter==67) {
    tft.drawBitmap(posx,posy,bn_C,39,42,TFT_WHITE); //C
  } else if (letter==89) {
    tft.drawBitmap(posx,posy,bn_Y,39,42,TFT_WHITE); //Y
  } else if (letter==76) {
    tft.drawBitmap(posx,posy,bn_L,39,42,TFT_WHITE); //L
  } else if (letter==87) {
    tft.drawBitmap(posx,posy,bn_W,39,42,TFT_WHITE); //W
  } else if (letter==77) {
    tft.drawBitmap(posx,posy,bn_M,39,42,TFT_WHITE); //M
  } 
}

// Wordtrain on the main 14seg
void wordtrain(String str, int delaytime) {
  int vfd = 30;

  char ltgp[str.length()+7];
  str.toCharArray(ltgp, str.length()+6);
  for (int i=0; i<str.length(); i++) {
    ltgp[str.length()+2-i] = ltgp[str.length()-1-i];
  }

  ltgp[0] = 32;
  ltgp[1] = 32;
  ltgp[2] = 32;
  ltgp[str.length()+3] = 32;
  ltgp[str.length()+4] = 32;
  ltgp[str.length()+5] = 32;

  for (int i = 0; i<(str.length()+3); i++) {
    charcall(ltgp[i],0);
    charcall(ltgp[i+1],1);
    charcall(ltgp[i+2],2);
    delay(delaytime);
    tft.drawBitmap( 3,60,bn_ALL,39,42,tft.color565(vfd,vfd,vfd));
    tft.drawBitmap(42,60,bn_ALL,39,42,tft.color565(vfd,vfd,vfd));
    tft.drawBitmap(81,60,bn_ALL,39,42,tft.color565(vfd,vfd,vfd));
  }

  delay(1000-delaytime);
}

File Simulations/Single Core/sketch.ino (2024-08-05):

// For the rotary encoder theres an example code here:
// https://wokwi.com/projects/304184298969236032
// and the SW pin works just like a normal pushbutton
//
// There were no motors or vibrators here, so I used an LED and a resistor
// in this case


#define ROT_SW 19  // pushbutton of encoder
#define ROT_DT 18  // data pin of encoder
#define ROT_CL 5   // clock of encoder 

#define MOT_OUT 4  // motor out (LED in this case) 


void setup() {
  // put your setup code here, to run once:
  Serial.begin(115200);
  pinMode(ROT_SW, INPUT);
  pinMode(ROT_DT, INPUT);
  pinMode(ROT_CL, INPUT);
  pinMode(MOT_OUT, OUTPUT);
}

int lastClk = HIGH;
int BPM = 100;

void loop() {
  int newClk = digitalRead(ROT_CL);

  if (newClk != lastClk) {
    // There was a change on the CLK pin
    lastClk = newClk;
    int dtValue = digitalRead(ROT_DT);

    if (newClk == LOW && dtValue == HIGH) {
      BPM += 1;
      Serial.println(BPM);
    }
    if (newClk == LOW && dtValue == LOW) {
      BPM -= 1;
      Serial.println(BPM);
    }
  }

  if(digitalRead(ROT_SW)==LOW) {
    float HIGH_T = 0.1;
    float LOW_T = 60.0/BPM - HIGH_T;
    for (;;) {
      digitalWrite(MOT_OUT, HIGH);
      delay(HIGH_T*1000);
      digitalWrite(MOT_OUT, LOW);
      delay(LOW_T*1000);
      Serial.println(digitalRead(ROT_SW));
      if(digitalRead(ROT_SW)==LOW) {
        break;
      }
    }
    delay(1000);
  }
}
